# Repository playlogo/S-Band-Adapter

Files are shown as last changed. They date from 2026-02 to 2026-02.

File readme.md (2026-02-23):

# S-Band Adapter

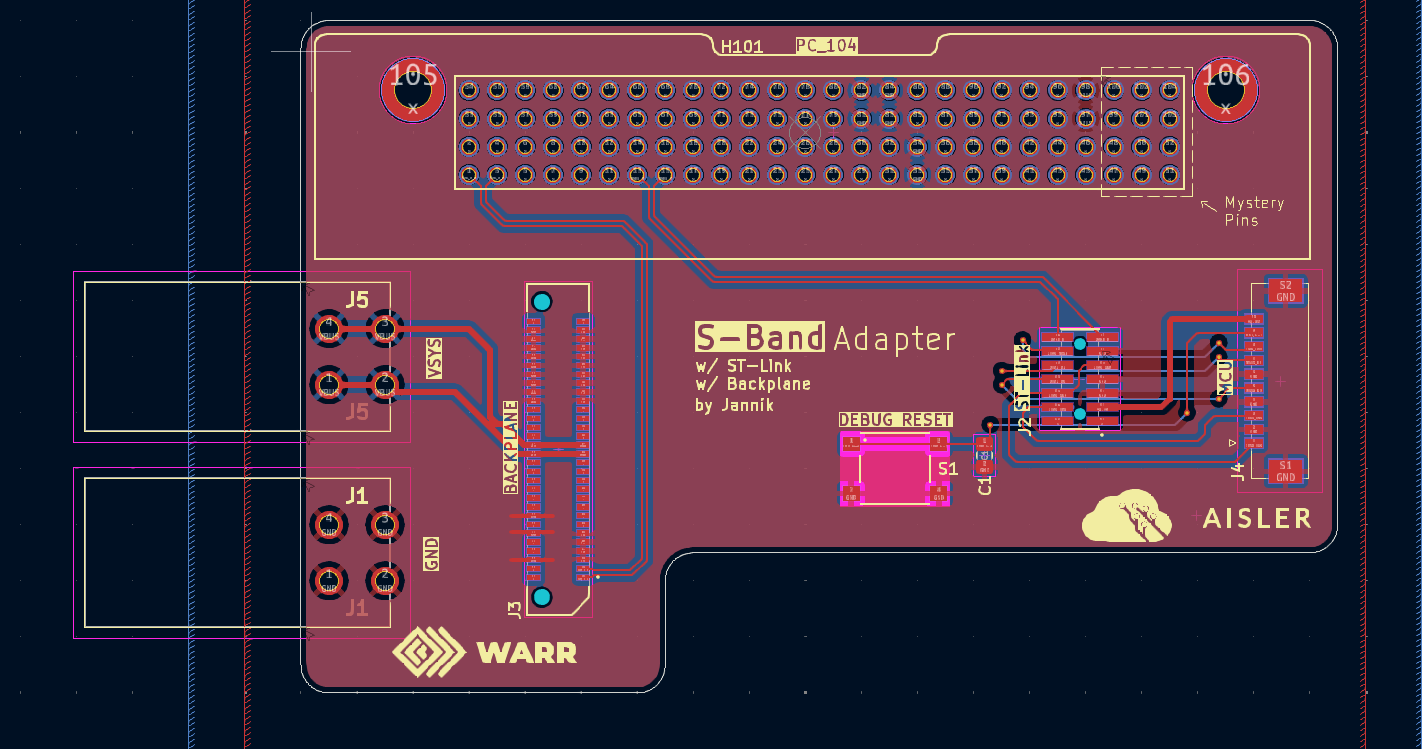
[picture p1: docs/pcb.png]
PCB (https://kicanvas.org/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)

*(image might be outdated, check interactive viewer for latest version)*

**Notes:**

- Under 10x10 cm
- Designed to get stacked *on top* of the S-Band module
- Passes ERC & DRC

**Links:**

- [Interactive PCB View (powered by KiCanvas, always up to date)](https://kicanvas.org/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)

## Components

**SMD Parts:**

- 2x [`CT3151SP`](https://www.digikey.de/de/products/detail/cal-test-electronics/CT3151SP-2/6005547): Banana plugs for VBat & GND - *[footprint](https://componentsearchengine.com/part-view/CT3151SP-2/Cal%20Test)*
- 1x [`FTSH‑107‑01‑L‑DV‑K‑A`](https://www.digikey.de/de/products/detail/samtec-inc/FTSH-107-01-L-DV-K-A/7443623): ST-Link debug connector, uses UART A from PC104 - *[footprint](https://www.snapeda.com/parts/FTSH-107-01-L-DV-K-A/Samtec%20Inc./view-part/?welcome=home&ref=digikey)*
- 1x [`ERF8-030-05.0-L-DV-TR`](https://www.digikey.de/de/products/detail/samtec-inc/ERF8-030-05-0-L-DV-TR/6613294): Move Backplane connector - *[footprint](https://www.snapeda.com/parts/ERF8-030-05.0-L-DV-TR/Samtec%20Inc./view-part/?ref=digikey)*
- 1x [`Molex 53261–1071 10pin`](https://www.digikey.de/de/products/detail/molex/0532611071/699102): S-Band MCU Debug Connector - Same MCU Debug connector on S-Band module - *[footprint](https://www.snapeda.com/parts/532611071/Molex/view-part/?ref=digikey)*
- S-Band connector:
  - Either set of two proper 52 Pin 2.54 Pitch connectors like [these overpriced ones (ESQ-126-39-G-D)](https://www.digikey.de/de/products/detail/samtec-inc/ESQ-126-39-G-D/3601055)
  - Or just a bunch of female and male 2.54mm Pitch connectors cut and combined to get 4 rows x 26 Pins (female for S-Band board, male for this Adapter) - maybe bad idea, since you then cannot stack more than one board on top of the S-Band module...
- 1x 0805 100nF capacitor
- 1x Würth 430152050826 Tactile Switch

**Cables:**

- Adapter Backplane female to Backplane female: Possibly a [Samtec ERCD with 30pos ? - looks very expensive, who even selected the Backplane connector, maybe they know which cable to use...](https://www.samtec.com/products/ercd#)
- S-Band MCU Debug Connector: [Molex PicoBlade 1.25mm, Female-to-Female, 300.00mm Length, 10 Circuits](https://www.molex.com/en-us/products/part-detail/151341003) - Pin order on one side has to be reversed... See image below, `C` should come out on the 3rd from the bottom and not 3rd from top, can easily be done with a screwdrivers

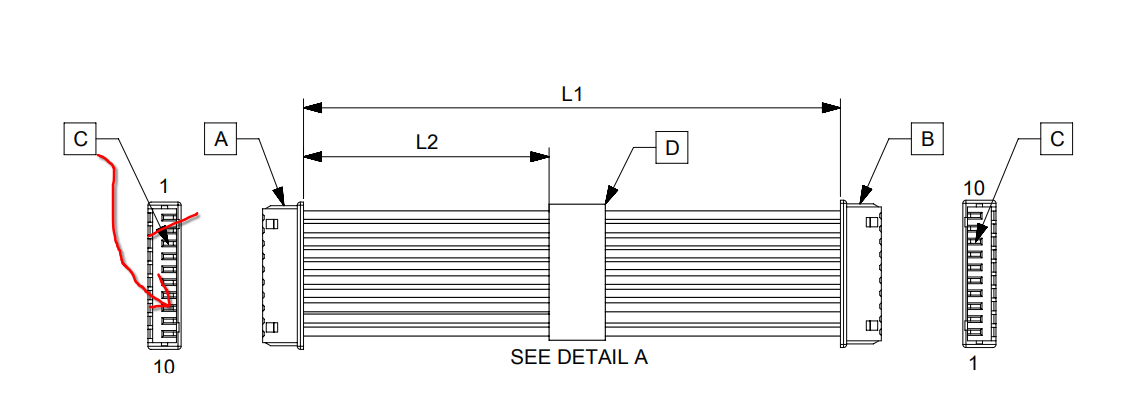
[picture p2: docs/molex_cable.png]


## Schematic

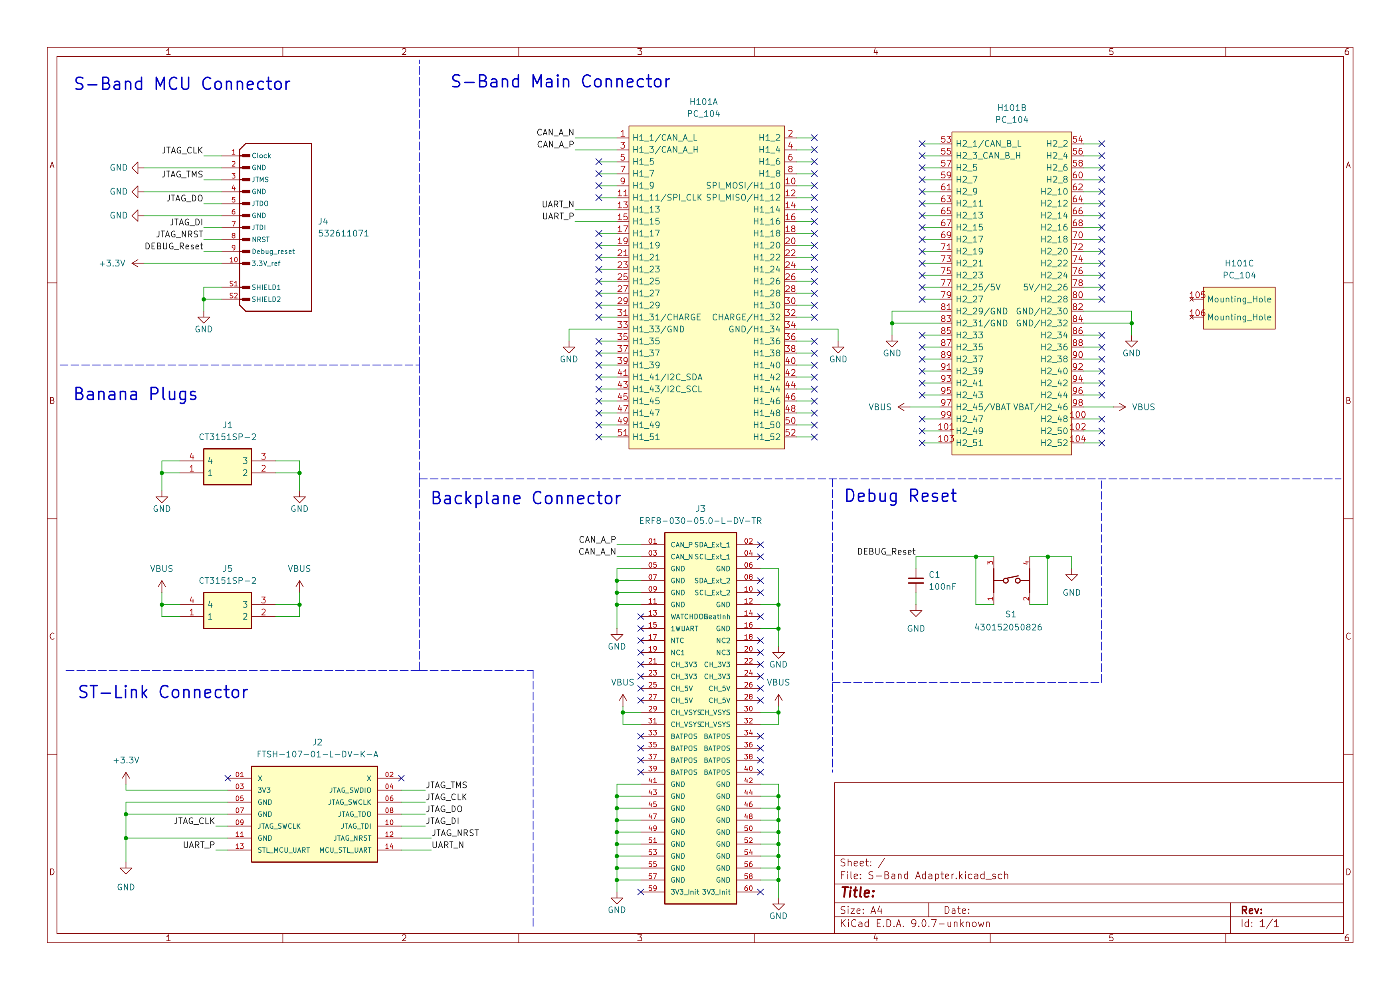
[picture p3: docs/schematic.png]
Scheamtic


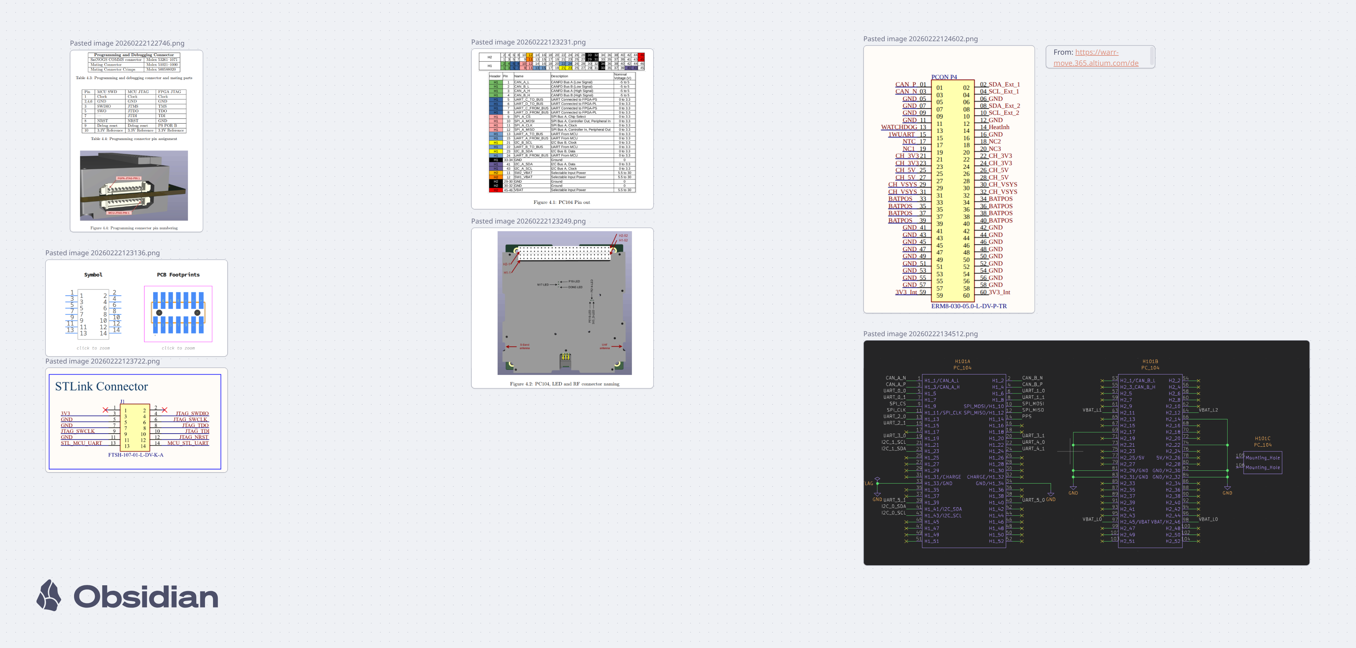
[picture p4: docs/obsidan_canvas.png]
Obsidian canvas


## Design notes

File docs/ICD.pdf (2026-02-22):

## Interface Control Document

SatNOGS COMMS

Version 1.6

SatNOGS COMMS
Interface Control Document

# Contents

1 Changelog | 3
2 Introduction | 5
3 Mechanical interface | 6
4 | Electrical Interfaces | 8
5 FPGA SoM | 16
6 Software Interfaces | 22
Version 1.6 | 1 of 45 | © Libre Space Foundation

SatNOGS COMMS
Interface Control Document
7 Performance Measurements | 25
8 Environmental Specifications | 39
9 Material List | 41
10 Interfaces Data Sheet | 42
Version 1.6 | 2 of 45 | © Libre Space Foundation

SatNOGS COMMS
Interface Control Document

# 1. Changelog

Version | Date | Changes
1.0 | Dec 18, 2023 | No Changes
1.1 | Dec 29, 2023 | No Changes
1.2 | Mar 19, 2024 | Updates for PCB v0.3.1
1.3 | Apr 30, 2024 | No Changes
1.4 | Nov 05, 2024 | No Changes
1.5 | Dec 10, 2024 | • Merged "Subsystem Interface" section with "Electrical interfaces" • Updated mechanical specifications to in- clude the bottom shield • Updated connector part numbers and pinout, added mating connector parts • Added FPGA SoM documentation • Update Software Interfaces chapter • Added "Environmental Specifications", "Performance Measurements", and "Mate- rial List" sections
1.5.1 | Dec 10, 2024 | Fix static GitLab pipeline
1.5.2 | Dec 18, 2024 | No changes
1.6 | | Add more details for RF measurements
Version 1.6 | 3 of 45 | © Libre Space Foundation

SatNOGS COMMS
Interface Control Document

## 1.1 Acronyms

AGC Automatic Gain Control

API Application programming interface

BER Bit Error Rate

BPF Band Pass Filter

CAN Controller Area Network

FPGA Field Programmable Gate Array

GMII Gigabit Media Independent Interface

gRPC gRPC Remote Procedure Calls

HDF5 Hierarchical Data Format

I2C Inter-Integrated Circuit

IC Integrated Circuit

JTAG Joint Test Action Group

LO Local Oscillator

MCU Micro-Controller Unit

PA Power Amplifier

PCB Printed Circuit Board

PDN Power Distribution Network

RF Radio Frequency

RGMII Reduced Gigabit Media-Independent Interface

RSSI Received signal strength indication

SDR Software Defined Radio

SFCG Space Frequency Coordination Group

SMPS Switching Mode Power Supply

SPI Serial Peripheral Interface

TGT Target

UART Universal Asynchronous Receiver Transmitter

UHF Ultra High Frequency

VGA Variable Gain Amplifier

Version 1.6 | 4 of 45 | © Libre Space Foundation

SatNOGS COMMS
Interface Control Document

# 2. Introduction

This Interface Control Document (ICD) defines the interface requirements for integrating SatNOGS COMMS into a CubeSat. In this document, the mechanical interface of the board along with its environmental specifications and materials list are provided. Additionally, the electrical interfaces are described in detail. In particular, the SatNOGS COMMS system included 2 RF interfaces (UHF and S-band), 2 external reference clock interfaces, multiple communication interfaces, and an interface for an FPGA SoM daughter board. For these interfaces, their position on the board along with pinout and other required electrical information are described. Moreover, key performance measurements, such as the power consumption in various operational states, are provided. Finally, the software interfaces of the system are also outlined in this document.

Version 1.6 | 5 of 45 | © Libre Space Foundation

SatNOGS COMMS
Interface Control Document

# 3. Mechanical interface

## 3.1 Dimensions

PCB dimensions, mounting holes, PC104 connector type and location follow LibreCube [1] standard, with the exception of the height of the bottom EMI shield. The PC104 interface connectors are SAMTEC ESQ-126–39–G-D. A mechanical drawing of the outline and mounting hole locations is shown in Figure 3.1 and the respective one for its side view along with an isometric view is shown in Figure 3.2.

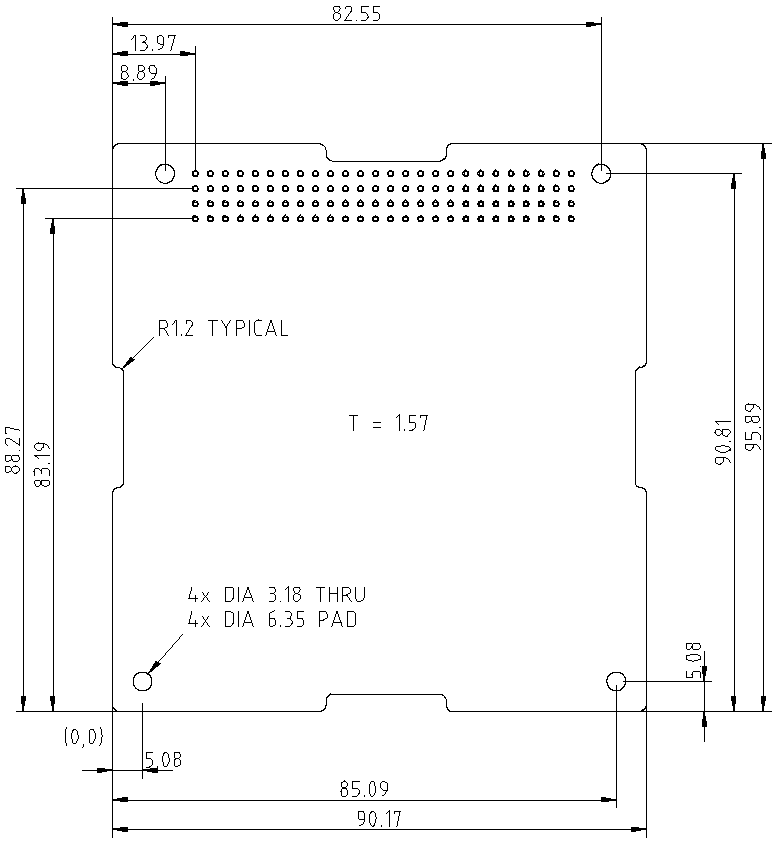
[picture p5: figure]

Figure 3.1: LibreCube mechanical drawing (mm)

Version 1.6 | 6 of 45 | © Libre Space Foundation

SatNOGS COMMS
Interface Control Document

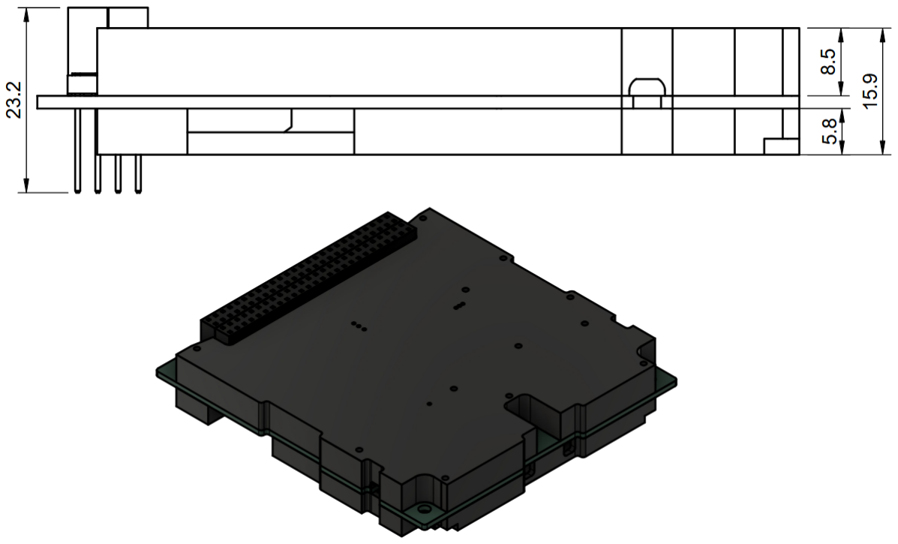
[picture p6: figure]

Figure 3.2: Side view dimensions (mm)

## 3.2 Mass Budget

# | Component | Material | Mass (grams)

1 | PCB | FR4 and copper | 31.1
2 | Passive Components | NA | 7.1
3 | ICs | NA | 16.7
4 | Connector | NA | 6.0
5 | Top Shield | Al 7075 | 80
6 | Bottom Shield | Al 7075 | 50
7 | Screws | A4 Stainless Steel | 4.1
TOTAL | | | 195g (±10g)

Table 3.1: Mass Budget Table

Version 1.6 | 7 of 45 | © Libre Space Foundation

SatNOGS COMMS
Interface Control Document

# 4. Electrical Interfaces

## 4.1 BUS Connector

SatNOGS COMMS connects to a CubeSat bus via a PC–104 connector. The connector type used is the SAMTEC ESQ-126–39–G-D. Regarding pin assignment, it is based on Librecube standard [1]. As far as pin numbering and header naming is concerned, again the Librecube standard is followed and Figure 4.1 contains all necessary information.
For subsystem communication the following interfaces are available on the PC–104 connector:
- Two CAN-FD interfaces backward compatible with CAN-2.0. CAN-FD fulfills interconnect link speed requirements, while subsystems only capable of CAN-2.0 can use SPI for data transfer and CAN-2.0 for control. The CAN transceiver used on SatNOGS COMMS is the TCAN334GDCNT. Additionally, it is possible during the order configuration phase to select whether the 120 Ohm CAN termination resistors will be soldered on SatNOGS COMMS or not. Details about the electrical specifications of the interface can be found in Table 10.3.
- One SPI interface with a maximum link speed of 8Mbps. Details about the electrical specifications of the interface can be found in Table 10.2.
- Two I2C interfaces. Details about the electrical specifications of the interface can be found in Table 10.8.
- Two UART from the MCU. Details about the electrical specifications of the interface can be found in Table 10.7.
- One UART from the FPGA. Details about the electrical specifications of the interface can be found in Table 10.7.

Note that only the CAN interface has been subjected to environmental tests so far.

Version 1.6 | 8 of 45 | © Libre Space Foundation

SatNOGS COMMS
Interface Control Document

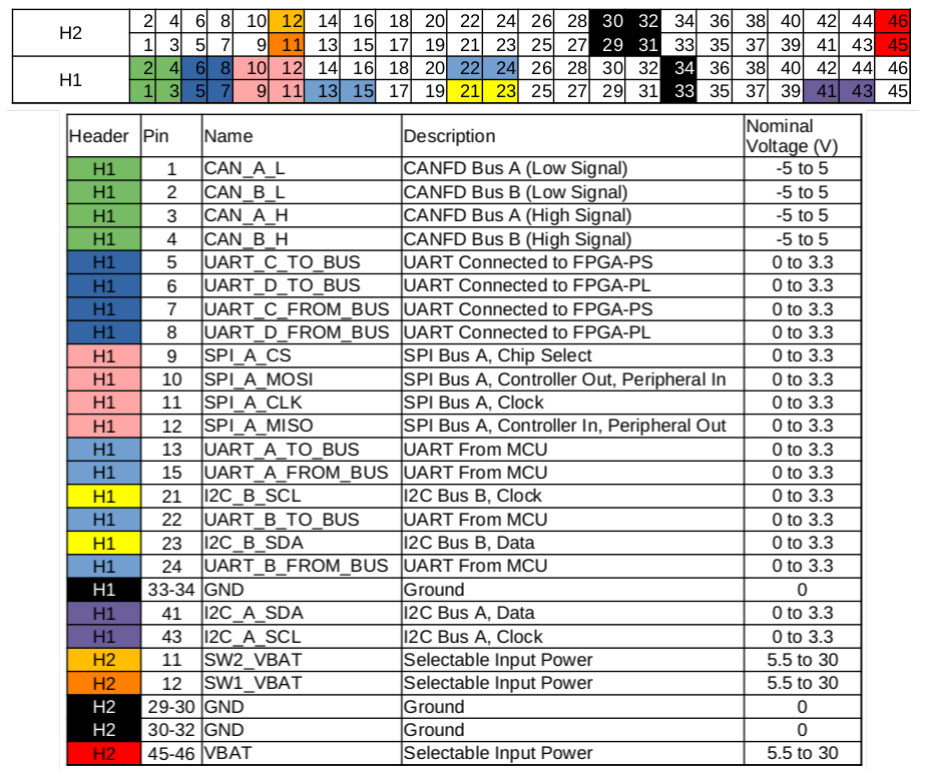
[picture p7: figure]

Figure 4.1: PC104 Pin out

Version 1.6 | 9 of 45 | © Libre Space Foundation

SatNOGS COMMS
Interface Control Document

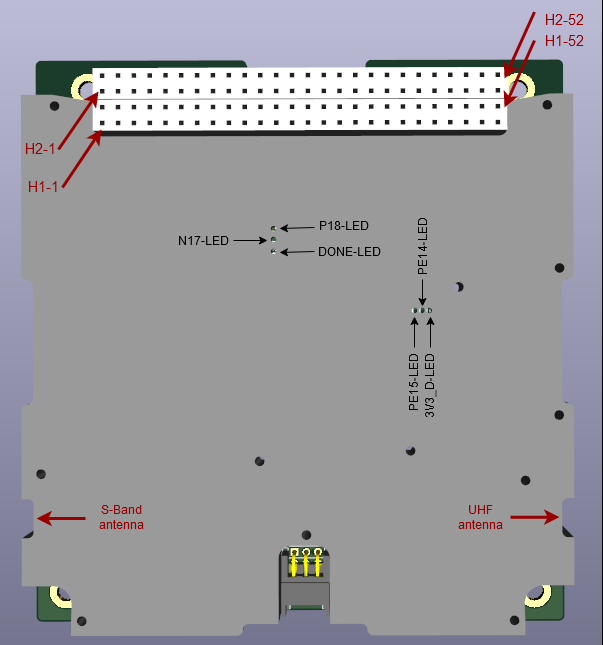
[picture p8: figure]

Figure 4.2: PC104, LED and RF connector naming

Regarding the power supply options, one can notice that three options are available. The user can select among those using solder jumpers, which are soldered during the order configuration stage. As mentioned in Figure 4.1, the input voltage range of SatNOGS COMMS is 5.5V to 30V.

## 4.2 Antenna Deployment Connector

The connector used for the antenna deployment interface along with its mating parts is provide in Table 4.1. The pin assignment is provided in Table 4.2 and the pin numbering is shown in Figure 4.3. The antenna deployment interface exposes two closed loop control endpoints, i.e. two deployment-detection line pairs.
Control signal lines are software configurable as either 3.3V Push-Pull or Open-Drain. Maximum input voltage in Open-Drain configuration is restricted to 5V by an ESD protection diode. Control signal current is limited to 22mA via 220Ω resistor (in the case of a 5V signal).
Detection signal lines are 3.3V compatible and software configured as Pull-Up, Pull-Down or Floating. Pull-Up and Pull-Down resistor value is 40kΩ ± 10kΩ. Each detection line is protected from over-voltage via a 5V ESD protection diode and a 1kΩ resistor.
Version 1.6 | 10 of 45 | © Libre Space Foundation

SatNOGS COMMS
Interface Control Document

Antenna Deployment Connector
SatNOGS COMMS connector | Harwin G125-MH10605L7P
Mating Connector | Harwin G125–2040696L0
Mating Connector Crimps | Harwin G125-FW20450L94

Table 4.1: Antenna deployment connector and mating parts

Pin | Function
1 | GND
2 | GND
3 | Deploy-B
4 | Detect-B
5 | Deploy-A
6 | Detect-A

Table 4.2: Antenna Deploy connector pin assignment

Figure 4.3: Antenna deployment interface pin numbering

## 4.3 Programming and debuging connectors

The connectors used to program and debug the MCU and the FPGA along with their mating parts are provided in Table 4.3. The supported interface for the FPGA is JTAG, while the MCU also supports SWD. Pin assignment is provided in Table 4.4, and pin 1 position is shown in Figure 4.4. Note that the debug reset pin on the MCU JTAG connector refers to a soft reset induced by the debug interface and not to the NRST pin of the MCU.

Version 1.6 | 11 of 45 | © Libre Space Foundation

SatNOGS COMMS
Interface Control Document

Programming and Debugging Connector
SatNOGS COMMS connector | Molex 53261–1071
Mating Connector | Molex 51021–1000
Mating Connector Crimps | Molex 500588020

Table 4.3: Programming and debugging connector and mating parts

Pin | MCU SWD | MCU JTAG | FPGA JTAG
1 | Clock | Clock | Clock
2,4,6 | GND | GND | GND
3 | SWDIO | JTMS | TMS
5 | SWO | JTDO | TDO
7 | — | JTDI | TDI
8 | NRST | NRST | GND
9 | Debug reset | Debug reset | PS POR B
10 | 3.3V Reference | 3.3V Reference | 3.3V Reference

Table 4.4: Programming connector pin assignment

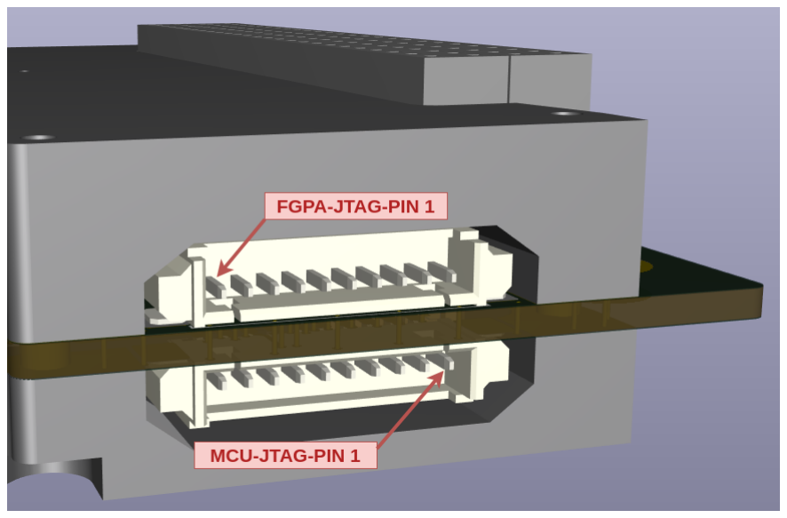
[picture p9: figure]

Figure 4.4: Programming connector pin numbering

## 4.4 RF Connectors

The connector used for the RF communication interfaces along with its mating part are provided in Table 4.5. The position of the UHF and S-Band interface on the board is noted in Figure 4.2.

Version 1.6 | 12 of 45 | © Libre Space Foundation

SatNOGS COMMS
Interface Control Document

Communication RF Connectors
SatNOGS COMMS connector | Molex 73415–0961
Mating Connector | Any MMCX
Mating Connector Crimps | Any MMCX

Table 4.5: Communication RF connectors and mating parts

The connector used for the 26MHz and 1PPS external reference clock interfaces along with its mating part is provided in Table 4.7. The position of the external reference clock interface on the board is noted in Figure 4.5. This figure only shows the cutouts on the EMI shield from which the interface cables exit the system. During assembly, the cables are connected before the EMI shield is placed and secured.
Some additional information on the external reference clock interface, is provided in Table 4.6.
Interface | Voltage Limit | Signal Type | Input Interface
1PPS | 0V to 3.3V | Rectanglular pulse | LMK1C1102DQF
26MHz | 600mV to 1500mV (peak to peak) AC Coupling | Rectanglular pulse Sine Clipped Sine | TS5A3157DCKR

Table 4.6: External Clock Interfaces

Reference Clock RF Connectors
SatNOGS COMMS connector | Wurth 66011102111302
Mating Connector | Same as mating crimp
Mating Connector Crimps | AmphenolRF 262111 MMCX Right Angle Crimp Plug RG-316DS RD-316 50 Ohm

Table 4.7: Reference clock RF connectors and mating parts

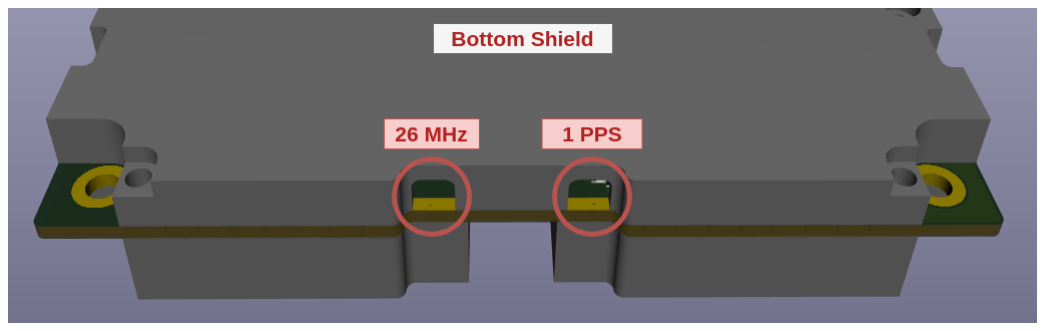
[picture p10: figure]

Figure 4.5: External clock reference interface

Version 1.6 | 13 of 45 | © Libre Space Foundation

SatNOGS COMMS
Interface Control Document

## 4.5 RGMII, UART & eMMC Connector

SatNOGS COMMS provides an RGMII interface which is connected to the PS part of the Zync SoC and, internally, it is fed by a GMII to RGMII adapter, which is wired to an IEEE 802.3–2008 [2] compliant gigabit ethernet controller. Up to 100 Mbps throughput on 1.8V operation has been achieved through this interface during testing.
The RGMII interface, a UART interface for debugging the SoM, along with some lines to access the eMMC memory are exposed on the connector listed in Table 4.8. The pinout of said connector is provided in Table 4.9 and the position of pin 1 is shown in Figure 4.6.

RGMII, UART, eMMC Connector
SatNOGS COMMS connector | Harwin G125-MH12605L3R
Mating Connector | Harwin G125–2042696L0
Mating Connector Crimps | Harwin G125-FW20150F94

Table 4.8: RGMII, UART, eMMC connector and mating parts

Pin | Function
1 | PHY_RESET
2 | 1.8V output
3 | RGMII-MDC
4, 7, 8, 22 | GND
5 | RGMII-MDIO
6 | PHY_INT
9 | RGMII-TXD0 from SoM
10 | RGMII-RXCLK to SoM
11 | RGMII-TXD1 from SoM
12 | RGMII-RXCTL to SoM
13 | RGMII-TXD2 from SoM
14 | RGMII-RXD0 to SoM
15 | RGMII-TXD3 from SoM
16 | RGMII-RXD1 to SoM
17 | RGMII-TXCLK from SoM
18 | RGMII-RXD2 to SoM
19 | RGMII-TXCTL from SoM
20 | RGMII-RXD3 to SoM
21 | MCU_MMC-D0
23 | MCU_MMC-CMD
24 | UART-RX to SoM
25 | MCU_MMC-CK
26 | UART-TX from SoM

Table 4.9: RGMII, UART & eMMC connector pinout

Version 1.6 | 14 of 45 | © Libre Space Foundation

SatNOGS COMMS
Interface Control Document

Figure 4.6: RGMII, UART & eMMC connector pin 1

## 4.6 ESD & Power protections

### 4.6.1 ESD

Most of the interfaces of SatNOGS COMMS include ESD protection in the form of clamping diodes placed as close as possible to the connectors. In particular, the protected interfaces are:

- MCU and FPGA JTAG
- PC–104 SPI, I2C and UART. Also resistors are included in-series after the diodes and before the components.
- Antenna deployment

Regarding the CAN interface on the PC–104, the selected CAN driver (TCAN334G) incorporates ESD protection.
Regarding the external reference clock 26MHz and 1PPS, the selected multiplexer and clock buffer incorporated ESD protection.

### 4.6.2 Power protection

The power system of SatNOGS COMMS is paired with an elaborate protection scheme able to protect the downstream components from overvoltage, undervoltage and excessive current draw. All major power rails on the board are automatically reset in the event of excessive current draw or overvoltage, while an MCU signal is required in addition to a proper voltage level for the RF and FPGA power rails to be enabled. For further details on the operation of the power protection system along with an FMEA analysis, please refer to the System Design Document.

Version 1.6 | 15 of 45 | © Libre Space Foundation

SatNOGS COMMS
Interface Control Document

# 5. FPGA SoM

This chapter details the various interfaces related to the FPGA SoM that can be hosted on SatNOGS COMMS. The electrical and mechanical interface characteristics required for a user to employ their own SoM on SatNOGS COMMS are provided.

## 5.1 RF Functionality

The baseband transceiver functionalities are listed below:

- Modulation: GMSK/GFSK, BPSK, QPSK
- Tx: ECC, CCSDS CC1/2 w/ and w/o RS, Rx: only CCSDS RS
- Framing encapsulation: CCSDS, IEEE 802.15.4
- Data Rates: UHF, up to 50 kbps, S-Band, up to 1 Mbps

In the default SatNOGS COMMS configuration with the Alinx AC7Z020, the SoM provides a 13-bit I/Q data interface with a sampling frequency up to 4MHz through which additional RF functionalities can be implemented.

## 5.2 Mechanical Interface

The FPGA SoM is mechanically attached to SatNOGS COMMS through nuts, bolts, and threaded spacers. In particular, the following parts are used:

- Nut M2 DIN934
- Bolt M2L8 DIN912
- Female to Female M2 L3, Knurled, Brass, Round Spacer

For the default SoM used in SatNOGS COMMS (the Alinx AC7Z020), the mounting is performed by placing the bold such that the bolt head contacts the bottom side of the board and the nut contacts the top side of the SoM, as shown in Figure 5.1. For the flight configuration, glue is applied to the nut and bolt. Regarding the relative position of the SoM mounting holes to the mezzanine connectors, a SoM KiCAD footprint has been created as part of the LibreWave project and it can be found in lsf-kicad-lib (https://gitlab.com/librespacefoundation/lsf-kicad-lib) under the footprint name LibreWave-SoM.

Version 1.6 | 16 of 45 | © Libre Space Foundation

SatNOGS COMMS
Interface Control Document

Figure 5.1: AC7Z020 SoM mounting

## 5.3 Electrical Interface

### 5.3.1 Mezzanine Connector Pinout

The connector used to interface SatNOGS COMMS with the FPGA SoM along with its mating part are provided in Table 5.1.
The functionalities of the mezzanine connector pins are provided in Table 5.2 and Table 5.3, while the naming of the two headers of the mezzanine connectors are shown in Figure 5.2.

RGMII, UART, eMMC Connector
SatNOGS COMMS connector | Panasonic AXK6A2337YG
Mating Connector | Panasonic AXK5A2137YG
Mating Connector Crimps | N/A

Table 5.1: FPGA SoM mezzanine connector and mating part

Version 1.6 | 17 of 45 | © Libre Space Foundation

SatNOGS COMMS
Interface Control Document

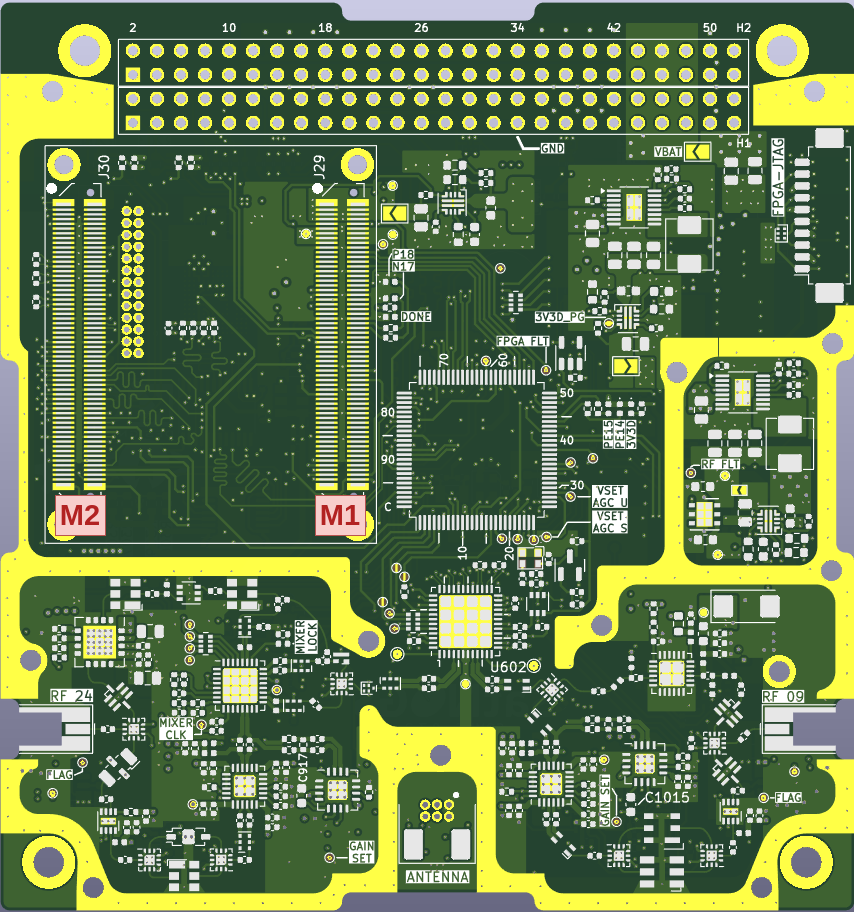
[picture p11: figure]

Figure 5.2: Mezzanine connector header numbering

Version 1.6 | 18 of 45 | © Libre Space Foundation

SatNOGS COMMS
Interface Control Document

H1

Header no | Overall no | Functionality
1, 2, 3, 4, 5, 6, 7, 8 | 1, 2, 3, 4,
| 5, 6, 7, 8 | 5V SoM input
11, 13, 15, 17 | 11, 13, 15, 17 | 3.3V SoM input
12, 14, 16, 18 | 12, 14, 16, 18 | 2.5V SoM input
9, 10, 19, 20, 29, 30, 39, 40, 49, 50, 59, 60, 69, 70, 79, 80, 89, 90, 99, 100, 109, 110 | 9, 10, 19, 20,
| 29, 30, 39, 40,
| 49, 50, 59, 60,
| 69, 70, 79, 80,
| 89, 90, 99, 100,
| 109, 110 | GND
22 | 22 | SPI-SEL
24 | 24 | SPI-MOSI
28 | 28 | SPI-MISO
37 | 37 | 1 PPS SoM clock input line 2
41 | 41 | SPI-CLK
52 | 52 | LED_1 output
54 | 54 | LED_2 output
55 | 55 | UART_2 RX to SoM
57 | 57 | UART_2 TX from SoM
72 | 72 | RX_INT (used as a generic IO
| | or to indicate an interrupt due to RF RX)
76 | 76 | IP_RESET (used as a generic IO
| | or to reset the IP cores)
81 | 81 | 100 MHz SoM clock input
111 | 111 | JTAG-TCK
113 | 113 | JTAG-TMS
115 | 115 | JTAG-TDO
116 | 116 | PS_POR_B (specific to some Xilinx FPGAs)
117 | 117 | JTAG-TDI
118 | 118 | FPGA_DONE (also drives a LED)

Table 5.2: Mezzanine connector H1 pinout

Version 1.6 | 19 of 45 | © Libre Space Foundation

SatNOGS COMMS
Interface Control Document

H2

Header pin | Connector pin | Functionality
9, 10, 29, 20, 29, 30, 39, 40, 49, 50, 59, 60, 69, 70, 79, 80, 89, 90, 99, 100, 109, 110, | 129, 130, 139, 140, 149, 150,
| 159, 160, 169, 170, 179, 180,
| 189, 190, 199, 200, 209, 210,
| 219, 220, 229, 230 | GND
1 | 121 | LVDS-TXDP from SoM
3 | 123 | LVDS-TXDN from SoM
25 | 145 | LVDS-RXDP Sband to SoM
27 | 147 | LVDS-RXDN Sband to SoM
31 | 151 | LVDS-RXDN UHF to SoM
33 | 153 | LVDS-RXDP UHF to SoM
41 | 161 | LVDS-RXCLKN to SoM
43 | 163 | LVDS-RXCLKP to SoM
52 | 172 | LVDS-TXCLKP from SoM
54 | 174 | LVDS-TXCLKN from SoM
61 | 181 | RGMII-RXCLK to SoM
63 | 183 | RGMII-RXCTL to SoM
65 | 185 | RGMII-RXD0 to SoM
66 | 186 | PHY_INT
67 | 187 | RGMII-RXD1 to SoM
71 | 191 | RGMII-RXD2 to SoM
72 | 192 | 1 PPS SoM clock input line 1
73 | 193 | RGMII-RXD3 to SoM
74 | 194 | MMC CK
75 | 195 | RGMII-TXCTL from SoM
76 | 196 | MMC D0
77 | 197 | RGMII-TXCLK from SoM
78 | 198 | MMC CMD
81 | 201 | RGMII-TXD3 from SoM
83 | 203 | RGMII-TXD2 from SoM
84 | 204 | MMC D2
85 | 205 | RGMII-TXD1 from SoM
87 | 207 | RGMII-TXD0 from SoM
92 | 212 | MMC D1
94 | 214 | PHY_RESET
96 | 216 | UART_1 TX from SoM
98 | 218 | UART_1 RX to SoM
102 | 222 | RGMII-MDC
112 | 232 | MMC D3
114 | 234 | UART_0 RX to SoM
116 | 236 | UART_0 TX from SoM
118 | 238 | RGMII-MDIO
119, 120 | 239, 240 | Configurable Pull Up/Down

Table 5.3: Mezzanine connector H2 pinout

Version 1.6 | 20 of 45 | © Libre Space Foundation

SatNOGS COMMS
Interface Control Document

### 5.3.2 SoM Power Interfaces

The SoM is powered via a PDN implemented on SatNOGS COMMS. The voltage levels provided by this PDN along with their current limits are listed below:

- 5V power channel: SMPS (LT8610EMSE#PBF), shared with the RF subsystem, protected against overvoltage, undervoltage, and overcurrent events via an e-fuse (TPS259470A). Overvoltage limits range from 5.3 to 5.47V. Undervoltage limits are 4.75V (for a rising edge) and 4.5V (for a falling edge). Additionally, an undevoltage limit of 5.7V has been set for the input of the SMPS. The current limit stands at 0.59 A. Note that the 3.3V and 2.5V power channels draw from the 5V one, so the aforementined current limit cannot be fully exploited by the 5V power channel.
- 3.3V power channel: LDO (LD39100PU33RY), with a current output capability dependent on the ambient temperature. A current capability of 0.48 A is obtained for the case of 80 C ambient temperature.
- 2.5V power channel: LDO (MIC5320-JGYD6), with a current output capacity dependent on the ambient temperature. A current capability of 0.26 A is obtained for the case of 80 C ambient temperature.
Version 1.6 | 21 of 45 | © Libre Space Foundation

SatNOGS COMMS
Interface Control Document

# 6. Software Interfaces

## 6.1 Space Segment

SatNOGS-COMMS provide a reference firmware[3] based on the Zephyr-RTOS[4]. This firmware covers the majority of the functionality required from a COMMS subsystem. Moreover, the firmware provides extensive functionality to operate as OBC too, if the mission requires it. Special attention has been given on the design of the firmware, so mission specific code can be added, adapting to the user needs. For more information refer to the main firmware documentation available at [5].
In case a mission or user requirements dictate significant firmware modifications or even another RTOS, SatNOGS-COMMS provide the SatNOGS COMMS Control Library[6]. This is an interface library that controls the SatNOGS COMMS transceiver components. It relies on a peripheral abstraction layer, allowing users of the SatNOGS COMMS to build their own firmware with minimal effort.

## 6.2 Ground Segment

### 6.2.1 Telemetry API

SatNOGS provides an API for receiving acquired telemetry as well as signal acquisition parameters. For non real-time operation, raw telemetry data is uploaded directly to SatNOGS DB servers by SatNOGS Client, on predefined intervals. This API endpoint accepts HDF5 formatted files which include additional information and metadata of the scheduled SatNOGS Network observation. The telemetry data are then processed and forward to the InfluxDB database of SatNOGS Dashboards in order to be visualized. For real-time operation, SatNOGS Client forwards the telemetry data to a SatNOGS Yamcs server. The SatNOGS Yamcs server receives the data through a data link plugin which provides a gRPC interface for telemetry. In this case, telemetry data is still eventually forwarded to SatNOGS DB via the Yamcs server and a SatNOGS DB API data link plugin.

### 6.2.2 Telecommand API

SatNOGS provides an API allowing telecommand data transmission. SatNOGS Client gRPC interface is used to receive telecommands. These commands are

Version 1.6 | 22 of 45 | © Libre Space Foundation

SatNOGS COMMS
Interface Control Document

sent by the SatNOGS Yamcs server via a gRPC data link plugin. The client then forwards the telecommands to SatNOGS Radio in order to be encoded and transmitted via the SDR.

### 6.2.3 Telecommand and Telemetry Format

The default firmware of the SatNOGS-COMMS utilizes the CCSDS XTCE[7] to describe the available telecommands and telemetry responses, as well as the internal structure of each frame. Yamcs provides seamless integration with the CCSDS XTCE.

### 6.2.4 Control Software

For the reference firmware[3] the SatNOGS COMMS project provides a Yamcsbased control software[8]. This Yamcs based control software can be used to telecommand the transceiver from any of the available interfaces (RF, CAN, UART) as well as receive telemetry. This is accomplished using the CCSDS XTCE definition that ships with the reference firmware. The purpose of this software it to act as a starting point, so missions can build easily the entire mission control with minimal effort.

## 6.3 Health Status Telemetry

### 6.3.1 Temperature Sensor Positions

To interpret the temperature values received in the health status telemetry, it is required to know the positions of the temperature sensors on the board. There are three sensors used to measure ambient (PCB) temperature, UHF PA temperature, and S-band PA temperature. The positions of the aforementioned sensors are depived in Figure 6.1.

Version 1.6 | 23 of 45 | © Libre Space Foundation

SatNOGS COMMS
Interface Control Document

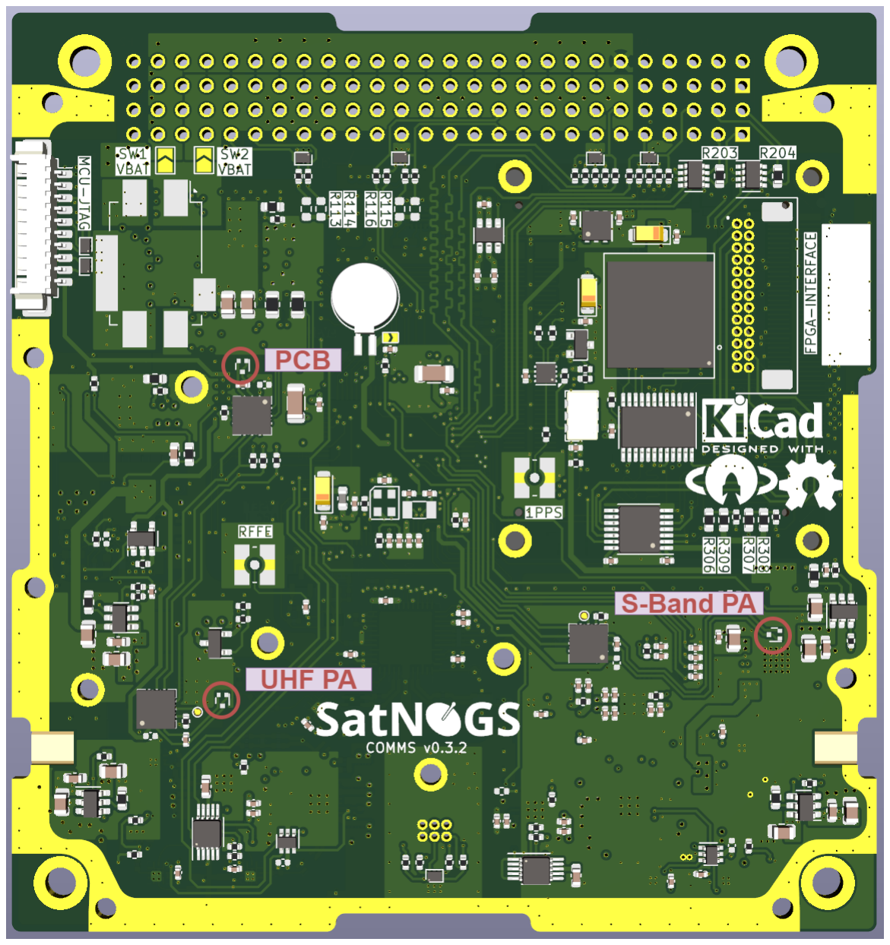
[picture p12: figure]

Figure 6.1: Temperature sensor positions

Version 1.6 | 24 of 45 | © Libre Space Foundation

SatNOGS COMMS
Interface Control Document

# 7. Performance Measurements

This chapter includes measurements related to the performance of the system, such as power consumption and RF characteristics.

## 7.1 Power Measurements

The power consumption of the system has been measured in various operational states. These measurements listed in Table 7.1 below refer to a 12V supply voltage. For a more detailed presentation along with comments on the test conditions refer to this spreadsheet. (https://cloud.libre.space/s/Rj7w5mWLiB8LQnf) Note that the measurements were made in v0.3, but the differences with the most recent version are very minor.

State no. | Avg Current [mA] | Peak Current [mA] | State Description
State 1 | 67 | NA | MCU peripherals initialized
State 2 | 57 | NA | State 1 + eMMC initialized
State 3 | NA | 91 | State 2 + eMMC write
State 4 | NA | 91 | State 2 + eMMC read
State 5 | 143 | NA | State 2 + FPGA on
State 6 | 203 | NA | State 2 + FPGA running petalinux
State 7 | 230 | NA | State 2 + FPGA stress petalinux
State 8 | 74 | NA | State 1 + RF open
State 9 | 71 | NA | State 8 + init AT86
State 10 | 370 | 641 | State 9 + full power TX UHF baseband
State 11 | 247 | NA | State 9 + RX UHF
State 12 | 185 | NA | State 9 + RX UHF
State 13 | 250 | NA | State 9 + RX UHF
State 14 | NA | NA | State 9 + RX UHF
State 15 | 467 | 718 | State 9 + fullpower TX S baseband
State 16 | 303 | NA | State 9 + RX S
State 17 | 267 | NA | State 9 + RX S
State 18 | 305 | NA | State 9 + RX S
State 19 | 245 | NA | State 9 + RX S
State 20 | 574 | 750 | State 15 + FPGA running petalinux
State 21 | 602 | 773 | State 15 + FPGA stress petalinux

Table 7.1: Current consumption in various operational states

Version 1.6 | 25 of 45 | © Libre Space Foundation

SatNOGS COMMS
Interface Control Document

## 7.2 Inrush current

Inrush current is a brief high current surge drawn when the device is turned ON. It generally occurs due to uncharged capacitors at the input of power supplies. The setup of the inrush current measurement was according to ECSS-E-ST-20–07C Rev.2. The setup consists of a Line Impedance Stabilization Network (LISN), a mechanical switch, a current probe and an oscilloscope for data acquisition. In this case, the current probe was replaced by two voltage probes and a 0.1 Ohm shunt resistor (RS010R1000FE12). To measure the current, the switch is pressed ON to power the device. A 12V battery was used as the power supply.
The inrush current waveform (Figure 7.1), can be characterized by two pulses. The first one, which is the main current draw, and the second one of much smaller amplitude. The small current draw, before the pulse emergence, is associated with the accuracy error of the oscilloscope and slight smoothing applied to the data for better visual representation.
The first current pulse reaches 13A and lasts around 100 µs. Immediately after, it reaches negative values up to -2A. The second pulse reaches around 3A and also lasts around 100 µs. After that, the board stabilizes to the nominal power consumption, when flashed with the particular firmware. It should be noted that the input voltage rise, when pressing the switch, is around 40 us. In case the input voltage has slowly risen to the desired level, the inrush current is much lower, although the number of pulses that occur increases. More details in https://gitlab.com/librespacefoundation/satnogs-comms/satnogs-comms-hardware/-/issues/490.

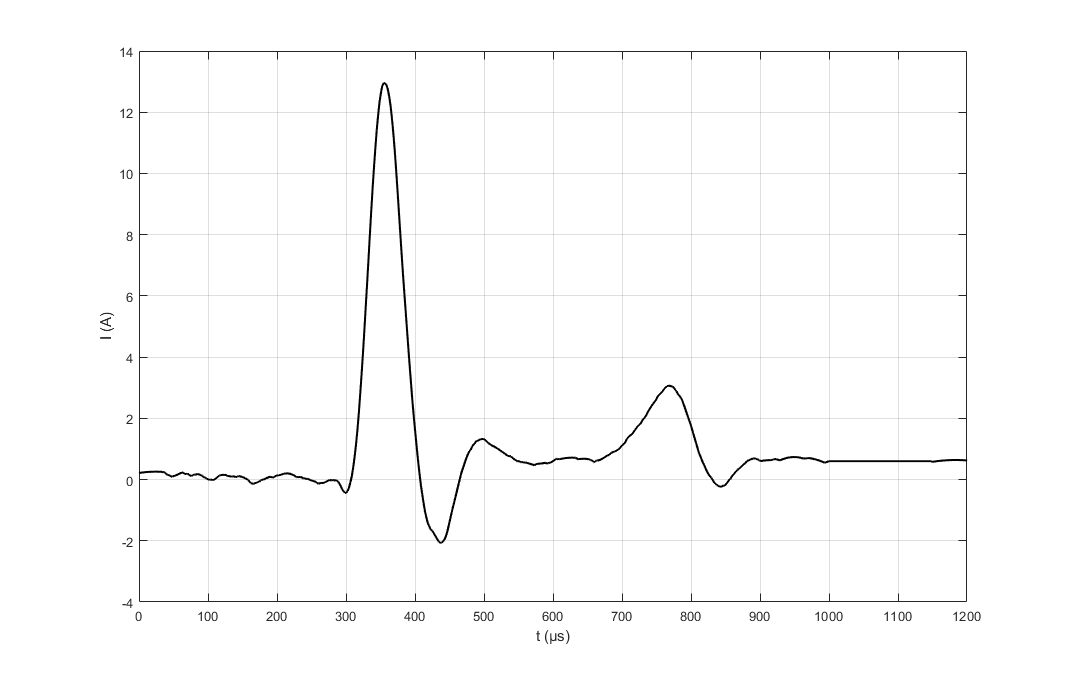
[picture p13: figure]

Figure 7.1: Inrush current of SatNOGS COMMS v0.3.2 — PHASMA version when first turned ON

Version 1.6 | 26 of 45 | © Libre Space Foundation

SatNOGS COMMS
Interface Control Document

## 7.3 RF Measurements

### 7.3.1 UHF Radio-Transmitter

The UHF radio is compliant with the SFCG 21–2R4 recommendations, peak indicated by the marker 2–1 in Figure 7.2 and the markers 2–1, 3–1, 4–1 in Figure 7.3.

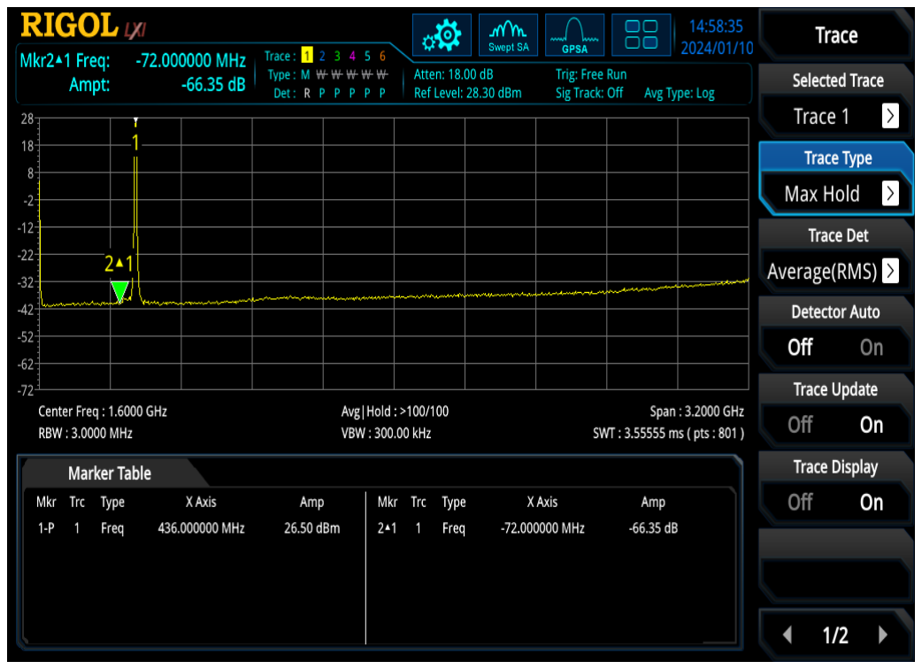
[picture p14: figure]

Figure 7.2: UHF spurious emissions, FSK–2, m = 1, TX power = +31 dBm, symbol rate = 50 kHz

Version 1.6 | 27 of 45 | © Libre Space Foundation

SatNOGS COMMS
Interface Control Document

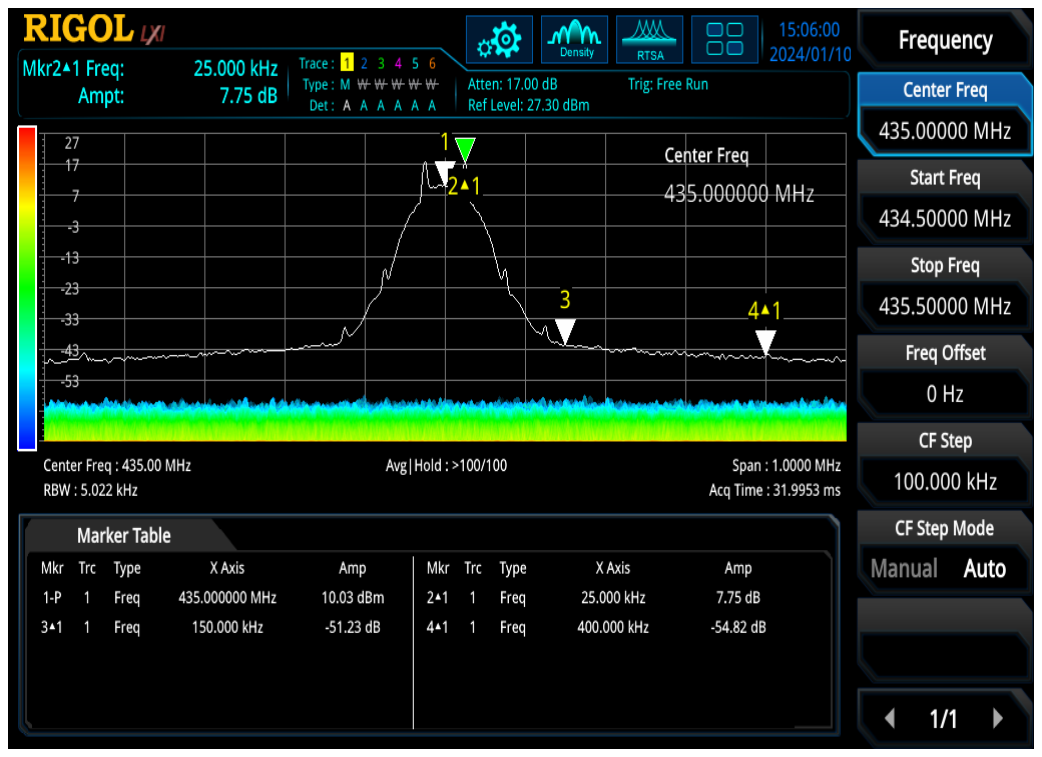
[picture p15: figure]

Figure 7.3: UHF spurious emissions, FSK–2, m = 1, TX power = +31 dBm, symbol rate = 50 kHz

The RF output power is not affected by the modulation index (0.5, 1, 1.5,
2) in FSK at 50 ksps. The following diagrams, Figure 7.4 and Figure 7.5, show that the RF output power and the DC power consumption are affected by the operating frequency, 401 and 435MHz. The measurements are done:
- with peak detector and maximum hold as trace type
- the measurement bandwidth (integrated) is 50kHz (FSK-2 at 50ksps) on 200kHz span
- temperature: 25 ◦C
- Dwell time: 60secs
- the DC power consumption is measured with joulescope and it is the average value of plateau, Figure 7.6
Version 1.6 | 28 of 45 | © Libre Space Foundation

SatNOGS COMMS
Interface Control Document

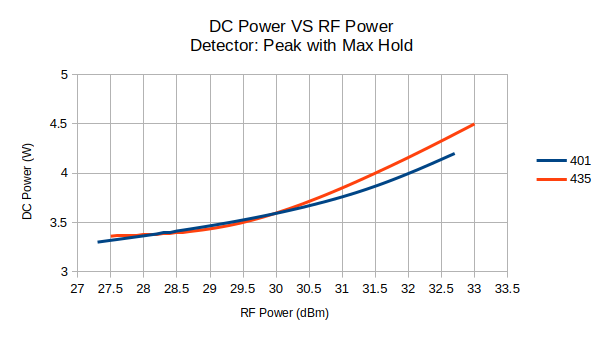
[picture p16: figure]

Figure 7.4: DC power vs TX RF power on UHF radio

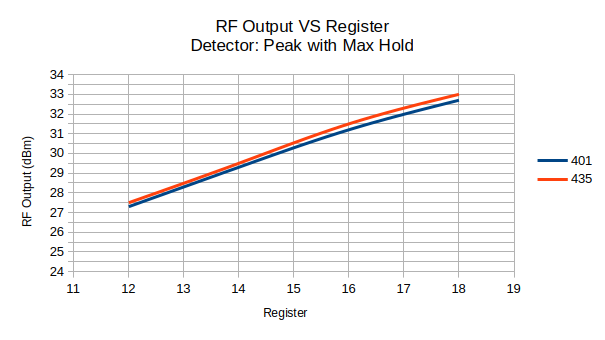
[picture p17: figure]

Figure 7.5: TX RF power vs AT86RF215 TX register on UHF radio

Version 1.6 | 29 of 45 | © Libre Space Foundation

SatNOGS COMMS
Interface Control Document

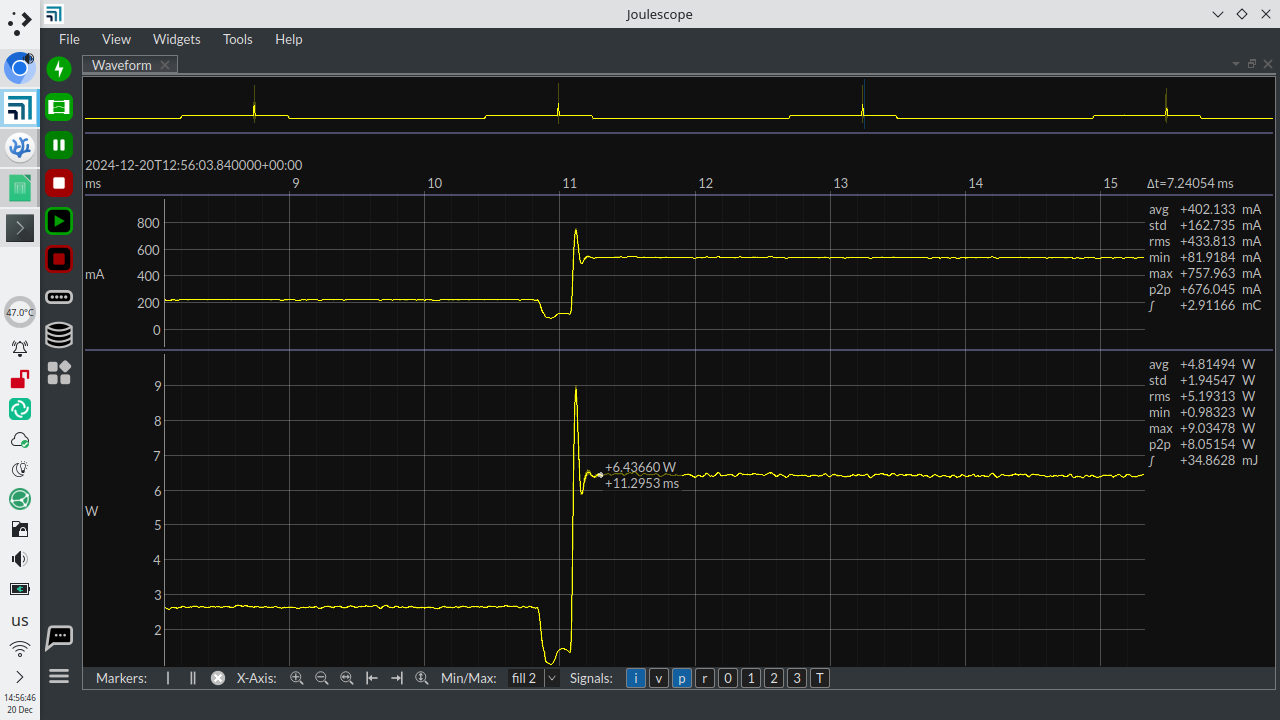
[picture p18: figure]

Figure 7.6: DC power consumption plateau measurement (an example)

The frequency step is 100Hz in the range 400MHz to 440MHz as defined by AT86RF215 IC.

### 7.3.2 UHF Radio-Receiver

The receive RF front end, can operate in two modes:

- AGC is enabled, Figure 7.7.
- AGC is disabled, and VGA is controlled by MCU, Figure 7.8.

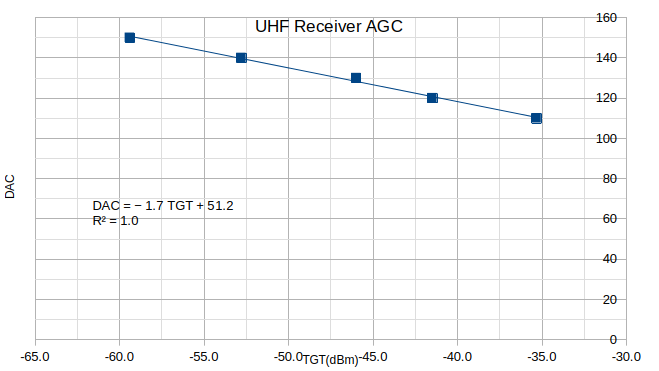
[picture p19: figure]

Figure 7.7: UHF AGC-ON, DAC 8-bit

Version 1.6 | 30 of 45 | © Libre Space Foundation

SatNOGS COMMS
Interface Control Document

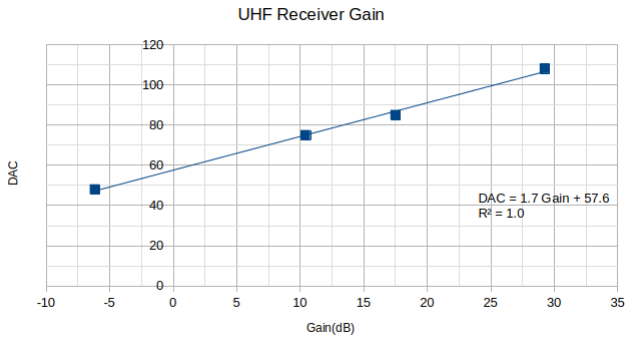
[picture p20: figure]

Figure 7.8: UHF AGC-OFF, DAC 8-bit

The suggested mode is AGC ON with TGT level −55dBm to achieve the largest dynamic range of 50dB. Some critical characteristics:

Noise Figure (dB) | 1.8
Maximum input (dBm) | +20

Table 7.2: UHF receiver

The TGT level is measured by using the RSSI of AT86RF215 with tolerance of ±5dB. The following table, Table 7.3, shows the DC power consumption in different RF input when the AGC in enabled and the output target is set on -52dBm ±5dB.

RF input (dBm) | RSSI (dBm) | Gain (dB) | DC power (W)
-20 | -41 | -21 | 1.69
-30 | -51 | -21 | 1.73
-40 | -51 | -11 | 1.8
-50 | -51 | -1 | 1.88
-60 | -51 | 9 | 1.98
-70 | -51 | 19 | 2.1
-80 | -51 | 29 | 2.25
-90 | -53 | 37 | 2.5
-100 | -61 | 39 | 2.5
-110 | -70 | 40 | 2.5

Table 7.3: RX UHF Radio dynamic range and DC power consumption, AGC ON with TGT -52dBm

The measurements are done:

- with CW RF input signal
- by using the wide BPF
Version 1.6 | 31 of 45 | © Libre Space Foundation

SatNOGS COMMS
Interface Control Document
- temperature: 25 ◦C
- Dwell time: 60secs
- the DC power consumption is measured with joulescope and it is the average value of plateau, Figure 7.6

The frequency step is 100Hz in the range 400MHz to 440MHz as defined by AT86RF215 IC.
Another important aspect is the BER performance of receiver. The following diagram and table, Figure 7.9 and Table 7.4, present the receiver sensitivity in different modulations.

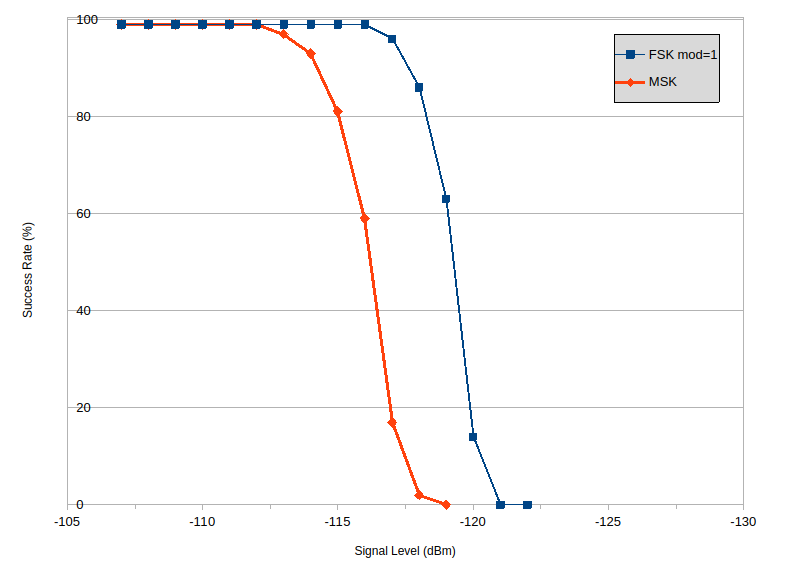
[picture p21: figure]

Figure 7.9: UHF Frame success rate for various signal levels

Modulation | ∆f (kHz) | Success Rate | Signal Level (dBm)
FSK—2, 50ksps | ±10 | 1099 of 1100 | -100
MSK, 50ksps | ±10 | 1100 of 1100 | -110

Table 7.4: RX UHF Radio Frequency offset sensitivity

Note:Better sensitivity is under investigation by the SatNOGS COMMS software team.

### 7.3.3 S-Band Radio-Transmitter

The S Band radio is compliant with the SFCG 21–2R4 recommendations, peak indicated by marker 2–1 in Figure 7.10 and markers 2–1, 3–1, 4–1 in Figure 7.11.

Version 1.6 | | 32 of 45 | © Libre Space Foundation

SatNOGS COMMS
Interface Control Document

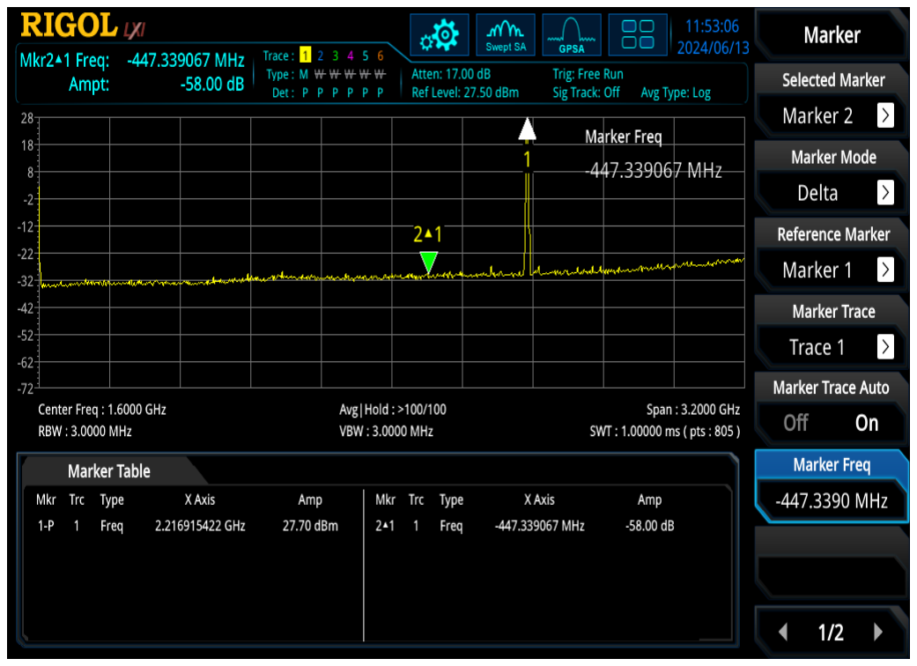
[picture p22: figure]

Figure 7.10: S Band spurious emissions with FSK–2, m = 0.5, TX power = +33 dBm, 400 kHz symbol rate

Figure 7.11: S Band spectrum mask for MSK, Input Power = 6.5dBm, symbol rate = 400 kHz

The RF output power is measured only on MSK at 400ksps. The following diagrams, Figure 7.12, Figure 7.13 and Figure 7.14, show that the RF output power and the DC power consumption are affected by the operating frequency, 2200MHz and 2290MHz. The measurements are done:

- with peak detector and maximum hold as trace type
- the measurement bandwidth (integrated) is 400kHz (MSK at 400ksps) on 600kHz span
Version 1.6 | 33 of 45 | © Libre Space Foundation

SatNOGS COMMS
Interface Control Document
- temperature: 25 ◦C
- Dwell time 60 secs
- the DC power consumption is measured with joulescope and it is the average value of plateau, Figure 7.6

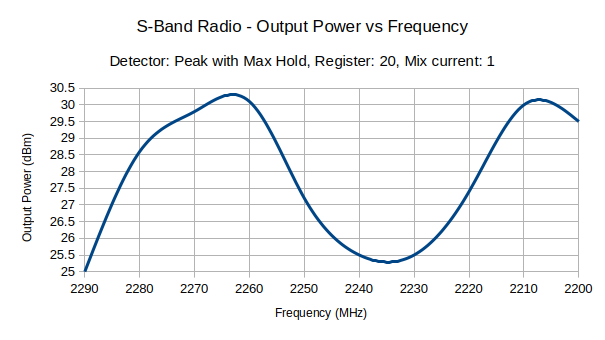
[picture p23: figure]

Figure 7.12: TX RF power vs Frequency on S-Band radio

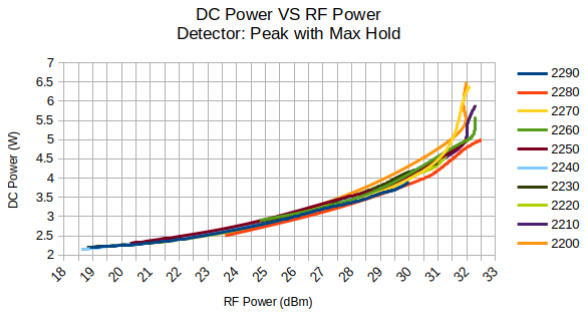
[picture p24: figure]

Figure 7.13: DC power vs TX RF power on S-Band radio

Version 1.6 | 34 of 45 | © Libre Space Foundation

SatNOGS COMMS
Interface Control Document

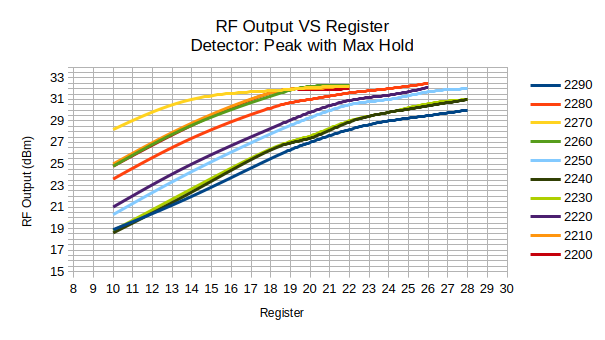
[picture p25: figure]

Figure 7.14: TX RF power vs AT86RF215 TX register on S-Band radio

The LO is selected according to the following table Table 7.5. The frequency step is 400Hz in the range 2200MHz to 2290MHz as defined by AT86RF215 IC. Option:Fine frequency step is possible after request.

LO (MHz) | IF (MHz) | RF (MHz) | Image (MHz)
182 | 2472 | 2290 | 2654
182 | 2462 | 2280 | 2644
216 | 2486 | 2270 | 2702
216 | 2476 | 2260 | 2692
216 | 2466 | 2250 | 2682
216 | 2456 | 2240 | 2672
216 | 2446 | 2230 | 2662
216 | 2436 | 2220 | 2652
216 | 2426 | 2210 | 2642
216 | 2416 | 2200 | 2632

Table 7.5: Look-up Table of LO frequencies of Transmitter

The mix current register of the RF mixer is set to 1.

### 7.3.4 S-Band Radio-Receiver

In the same manner with section subsection 7.3.2 are following the diagrams, Figure 7.15 and Figure 7.16.

Version 1.6 | 35 of 45 | © Libre Space Foundation

SatNOGS COMMS
Interface Control Document

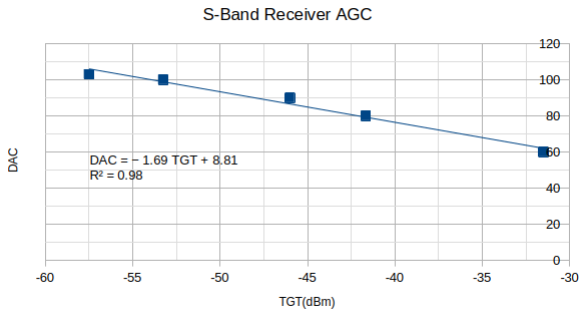
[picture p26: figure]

Figure 7.15: S-Band AGC-ON, DAC 8-bit

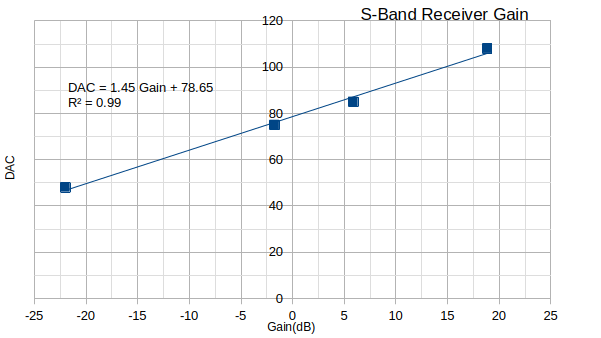
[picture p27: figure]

Figure 7.16: S-Band AGC-OFF, DAC 8-bit

The suggested mode is AGC ON with TGT level −55dBm to achieve the largest dynamic range of 40dB. Some critical characteristics:

Noise Figure (dB) | 2.2
Maximum input (dBm) | +27

Table 7.6: S-Band receiver

The TGT level is measured by using the RSSI of AT86RF215 with tolerance of ±5dB. The following table, Table 7.7, shows the DC power consumption in different RF input when the AGC in enabled and the output target is set on -52dBm ±5dB.

Version 1.6 | 36 of 45 | © Libre Space Foundation

SatNOGS COMMS
Interface Control Document
RF input (dBm) | RSSI (dBm) | Gain (dB) | DC power (W)
-20 | -48 | -28 | 2.22
-30 | -51 | -21 | 2.27
-40 | -51 | -11 | 2.34
-50 | -52 | -2 | 2.45
-60 | -52 | 8 | 2.57
-70 | -52 | 18 | 2.7
-80 | -59 | 21 | 2.83
-90 | -70 | 20 | 2.83
-100 | -78 | 22 | 2.8
-110 | -88 | 22 | 2.84

Table 7.7: RX S-Band Radio dynamic range and DC power consumption, AGC ON with TGT -52dBm

The measurements are done:

- with CW RF input signal
- by using the wide BPF
- temperature: 25 ◦C
- Dwell time: 60secs
- the DC power consumption is measured with joulescope and it is the average value of plateau, Figure 7.6

The LO is selected according to the following table Table 7.8. The frequency step is 400Hz in the range 2025MHz to 2110MHz as defined by AT86RF215 IC. Option:Fine frequency step is possible after request.

Image
(MHz)

IF
(MHz)

LO
(MHz)

RF
(MHz)

5th
LO
(MHz)

6th
LO
(MHz)

7th
LO
(MHz)
1635 | 2415 | 390 | 2025 | 1950 | 2340 | 2730
1640 | 2420 | 390 | 2030 | 1950 | 2340 | 2730
1650 | 2430 | 390 | 2040 | 1950 | 2340 | 2730
1660 | 2440 | 390 | 2050 | 1950 | 2340 | 2730
1670 | 2450 | 390 | 2060 | 1950 | 2340 | 2730
1706 | 2434 | 364 | 2070 | 1820 | 2184 | 2548
1716 | 2444 | 364 | 2080 | 1820 | 2184 | 2548
1726 | 2454 | 364 | 2090 | 1820 | 2184 | 2548
1736 | 2464 | 364 | 2100 | 1820 | 2184 | 2548
1746 | 2474 | 364 | 2110 | 1820 | 2184 | 2548

Table 7.8: Look-up Table of LO frequencies of Receiver

Version 1.6 | 37 of 45 | © Libre Space Foundation

SatNOGS COMMS
Interface Control Document

The mix current register of the RF mixer is set to 1.
Another important aspect is the BER performance of receiver. The following diagram and table, Figure 7.17 and Table 7.9, present the receiver sensitivity in different modulations.

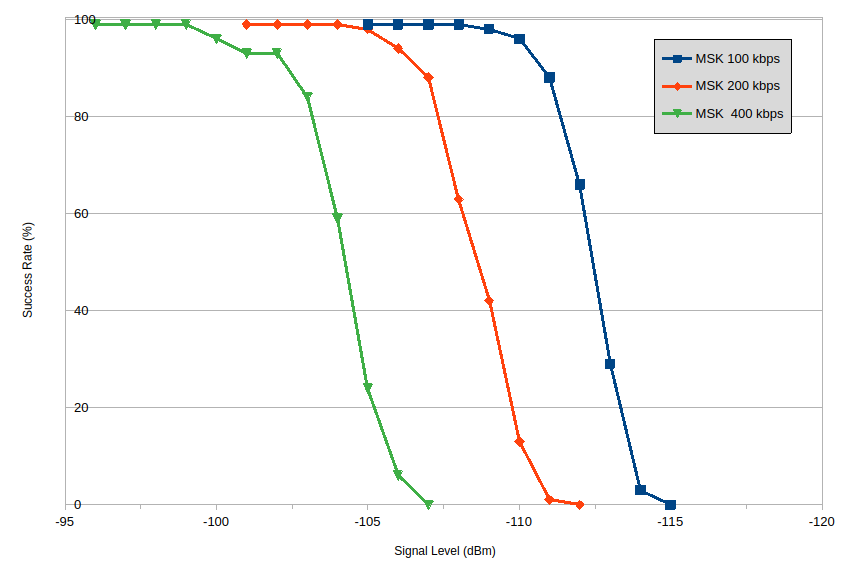
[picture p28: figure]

Figure 7.17: S-Band Frame success rate for various signal levels

Modulation | ∆f (kHz) | Success Rate | Signal Level (dBm)
MSK, 400ksps | ±60 | 1100 of 1100 | -96

Table 7.9: RX S-Band Radio Frequency offset sensitivity

Note:Better sensitivity is under investigation by the SatNOGS COMMS software team.

Version 1.6 | 38 of 45 | © Libre Space Foundation

SatNOGS COMMS
Interface Control Document

# 8. Environmental Specifications

This chapter outlines the system specifications related to its operational environment.

## 8.1 Operational Temperature

Based on the maximum and minimum operational temperatures of its components, the operational temperatures of SatNOGS COMMS range from −20° to 60° C. A component-level analysis is provided here. (https://cloud.libre.space/s/EdtgG9F3eb9kys9) As one can notice in the analysis, only a few resistors, capacitors, and inductors have been studied as samples, yet the analysis includes all the more complex integrated circuits. Additionally, a report from the most recent TVAC test can be found here. (https://gitlab.com/librespacefoundation/satnogs-comms/satnogs-comms-design-doc/-/jobs/artifacts/master/raw/build/environmental-test-report.pdf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)

## 8.2 Vibration Environment

The report from the most recent vibration test can be found here. (https://gitlab.com/librespacefoundation/satnogs-comms/satnogs-comms-design-doc/-/jobs/artifacts/master/raw/build/environmental-test-report.pdf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)

## 8.3 Electromagnetic Compatibility

### 8.3.1 Possible EM Emitters

Listed in Table 8.1 are potential EMI emitters on the board. This list mostly serves as a reference in case EMC debugging is required, because if detailed emission characterization is required (for example for a sensitive on—board payload), the emissions spectrum from the EMC test shall be used. Harmonics of the frequencies listed below are also possible to appear.
The report from the most recent EMC test is provided here. (https://gitlab.com/librespacefoundation/satnogs-comms/satnogs-comms-design-doc/-/jobs/artifacts/master/raw/build/emc-test-report.pdf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) Note that this test was conducted on SatNOGS COMMS v0.3.1. The upcoming SatNOGS COMMS v0.3.2 includes an EMI filter on the power input, which aims to alleviate the emissions which violate the limits in the provided test report.
Version 1.6 | 39 of 45 | © Libre Space Foundation

SatNOGS COMMS
Interface Control Document
Possible Emitter | Frequency
3.3V SMPS | 1.2 MHz
5V SMPS | 1.0 MHz
FPGA SoM 1V SMPS | 2.5 MHz
FPGA SoM 1.8V SMPS | 2.5 MHz
MCU HSE Crystal | 32 MHz
MCU LSE Crystal | 32.768 kHz
RF Transceiver Crystal | 26 MHz
FPGA Crystal | 100 MHz
LVDS | 64 MHz
RGMII | Depends on selected bus clock frequency
MCU-FPGA SPI | Depends on selected bus clock frequency
MCU-Transceiver SPI | Depends on selected bus clock frequency
Bus SPI | Depends on selected bus clock frequency
Bus UART | Depends on selected data rate
Bus I2C | Depends on selected bus clock frequency
SMBus | Depends on selected bus clock frequency
CAN-FD | Depends on selected data rate
CAN 2.0 | Depends on selected data rate

Table 8.1: Possible EMI emitters list

### 8.3.2 Grounding

The PCB is grounded through the PC-104 connector. So, there are no deliberate structure currents because the system has a single path to the satellite common ground (through the PC-104 connector). This grounding architecture is selected according to the NASA electrical grounding architecture technical handbook[9]. It must, however, be noted that the grounding of the EMI shield is not optimal. Instead of being connected to the satellite’s chassis ground (which, in turn, is connected to the common ground), the EMI shield is connected to the SatNOGS COMMS system ground and then to the satellite’s ground through the PC-104 connector. This structure results in a larger impedance on the path between the EMI shield and the common ground. Finally, it is noted that the ground of the RG ports is connected to the system ground.

## 8.4 Radiation Tolerance

Besides the power protection features aiming to increase radiation hardness against single event effects, SatNOGS COMMS employs aluminum shielding to protect its components from total ionizing dose faults. An analysis for a 6-year mission in a LEO orbit is provided in [10].

Version 1.6 | 40 of 45 | © Libre Space Foundation

SatNOGS COMMS
Interface Control Document

# 9. Material List

The list of materials contained in the SatNOGS COMMS system is provided here. (https://cloud.libre.space/s/SaeYA93L69b83R3)

Version 1.6 | 41 of 45 | © Libre Space Foundation

SatNOGS COMMS
Interface Control Document

# 10. Interfaces Data Sheet

INTERFACE DATA SHEET
| I/F Designation: | DC Power interface
ID | Source Circuit Specification | Ver | Iss
-1 | Bus voltage | 5.5V-30V input range
-2 | Bus current | 1.6A max @ 12V Bus voltage
-3 | Response to bus undervolt-age | All loads except MCU switch off automatically MCU is deactivated at 3.2V Bus voltage
-4 | Bus voltage (anomaly): | The load shall not be damaged when subjected to any bus voltage in the range 0V to 30V, steady-state or at any rate of change.

Table 10.1: DC Power Interface characteristics

INTERFACE DATA SHEET
| I/F Designation: | SPI interface
ID | Voltage, data rate and timing specification | Ver | Iss
-1 | Data rate | 8 Mbps for 3m total bus length between devices
-2 | Voltage range | 0V–3.3V
-3 | Voltage tolerance | -0.3V–5.5V
-4 | SPI clock frequency | Slave receiver mode: 100MHz max Slave mode transmitter/full duplex: 31MHz Slave mode transmitter/full duplex: 25MHz
-5 | NSS setup time | Min 2ns
-6 | NSS hold time | Min 1ns
-7 | Data input setup time | Min 2ns
-8 | Data input hold time | Min 1ns
-9 | Data input hold time | 1ns
-10 | Data output access time | 9ns–27ns
-11 | Data output disable time | Max 5ns
-12 | Data output valid time | Max 16ns
-13 | Data output hold time | Min 9ns

Table 10.2: SPI Interface characteristics

Version 1.6 | 42 of 45 | © Libre Space Foundation

SatNOGS COMMS
Interface Control Document

INTERFACE DATA SHEET
| I/F Designation: | CAN interface
ID | CAN Bus characteristics | Ver | Iss
-1 | Bus 1 | Compliant with ISO 11898–1[11] (CAN protocol specification version 2.0 part A, B) and CAN FD protocol specification version 1.0 Supports time triggered CAN (TT-FDCAN) specified in ISO 11898–4[12]
-2 | Bus 2 | Compliant with ISO 11898–1[11] (CAN protocol specification version 2.0 part A, B) and CAN FD protocol specification version 1.0
-3 | Receiver common mode in-put voltage | +/-12V
-4 | Bus fault protection | +/-58V
-5 | Max differential voltage be-tween CANH and CANL | +/-45V
-6 | Bus termination | 120 Ω at each end of the bus. Split termination is supported

Table 10.3: CAN Interface characteristics

INTERFACE DATA SHEET
| I/F Designation: | Antenna interface
ID | RF characteristics | Ver | Iss
-1 | UHF Impedance | 50 Ω
-2 | S-Band impedance | 50 Ω
Deployment control
-3 | Output type | Push-pull or Open-drain
-4 | Output voltage | Push-pull: 3.3V Open-drain: 5V
-5 | Output current | Max 18mA
Deployment detection
-6 | Input type | Pull-Up, Pull-Down, Floating or Analog
-7 | Input voltage | Nominal 3.3V (reference voltage for analog) Tolerant 5V (only Digital)
-8 | High threshold | 2V
-9 | Low threshold | 0.8V
-10 | Pull-up/Pull-down resistor | 40kΩ±10kΩ

Table 10.4: Antenna Interface characteristics

INTERFACE DATA SHEET
| I/F Designation: | External Clock interface
ID | RF characteristics, Voltage and timing specification | Ver | Iss
-1 | Impedance: 1PPS | 50 Ω
-2 | Impedance: RFFE-26MHz | 50 Ω
-3 | Voltage Level: 1PPS | 0V and 3.3V
-4 | Voltage Level: RFFE-26MHz | peak-to-peak amplitude: 600mV to 1600mV
-5 | Signal Type: 1PPS | Pulse
-6 | Signal Type: RFFE-26MHz | Pulse or Clipped Sine

Table 10.5: External Clock, 1PPS and 26MHz characteristics

Version 1.6 | 43 of 45 | © Libre Space Foundation

SatNOGS COMMS
Interface Control Document

INTERFACE DATA SHEET
| I/F Designation: | RGMII
ID | RGMII characteristics | Ver | Iss
-1 | Signal characteristics | Gigabit Ethernet Controller compliant with IEEE 802.3–2008 standard [2]
-2 | Data rate | 10/100/1000 Mbps
-3 | Voltage range | 0V 1.8V

Table 10.6: RGMII Interface characteristics

INTERFACE DATA SHEET
| I/F Designation: | UART
ID | UART characteristics | Ver | Iss
-1 | Type | Asynchronous
-2 | Data rate | User defined
-3 | Voltage range | 0V to 3.3V

Table 10.7: UART Interface characteristics

INTERFACE DATA SHEET
| I/F Designation: | I2C
ID | I2C characteristics | Ver | Iss
-1 | Type | Bidirectional
-2 | Data rate | 0.1/0.4/1.0 Mbps
-3 | Voltage range | 0V to 3.3V

Table 10.8: I2C Interface characteristics

Version 1.6 | 44 of 45 | © Libre Space Foundation

SatNOGS COMMS
Interface Control Document

# References

[1] LibreCube. LibreCube project. (https://librecube.gitlab.io/)
[2] IEEE. Ieee standard for information technology–telecommunications and information exchange between systems–local and metropolitan area networks–specific requirements part 3: Carrier sense multiple access with collision detection (csma/cd) access method and physical layer specifications, 2008.
[3] Libre Space Foundation. SatNOGS COMMS Firmware. (https://gitlab.com/librespacefoundation/satnogs-comms/satnogs-comms-software-mcu)
[4] Zephyr RTOS, (https://www.zephyrproject.org/) 2024.
[5] Libre Space Foundation. SatNOGS COMMS Software Documentation. (https://librespacefoundation.gitlab.io/satnogs-comms/satnogs-comms-software-mcu)
[6] Libre Space Foundation. SatNOGS COMMS Control Library. (https://gitlab.com/librespacefoundation/satnogs-comms/libsatnogs-comms)
[7] CCSDS. CCSDS Recommended Standard for XML Telemetric and Command Exchange, CCSDS 660.0-B-2. 2020.
[8] Libre Space Foundation. SatNOGS COMMS YAMCS Control Software. (https://gitlab.com/librespacefoundation/satnogs-comms/satnogs-comms-yamcs)
[9] NASA. ELECTRICAL GROUNDING ARCHITECTURE FOR UN-MANNED SPACECRAFT, (https://s3vi.ndc.nasa.gov/ssri-kb/static/resources/NASA-HDBK-4001.pdf) 1998.
[10] SatNOGS COMMS radiation shield analysis. (https://gitlab.com/librespacefoundation/satnogs-comms/satnogs-comms-hardware/-/issues/464)
[11] ISO/TC 22/SC 31. Road vehicles — Controller area network (CAN) — Part 1: Data link layer and physical signalling, (https://www.iso.org/standard/63648.html) 2015.
[12] ISO/TC 22/SC 31. Road vehicles — Controller area network (CAN) — Part 4: Time-triggered communication, (https://www.iso.org/standard/36306.html) 2004.
Version 1.6 | 45 of 45 | © Libre Space Foundation

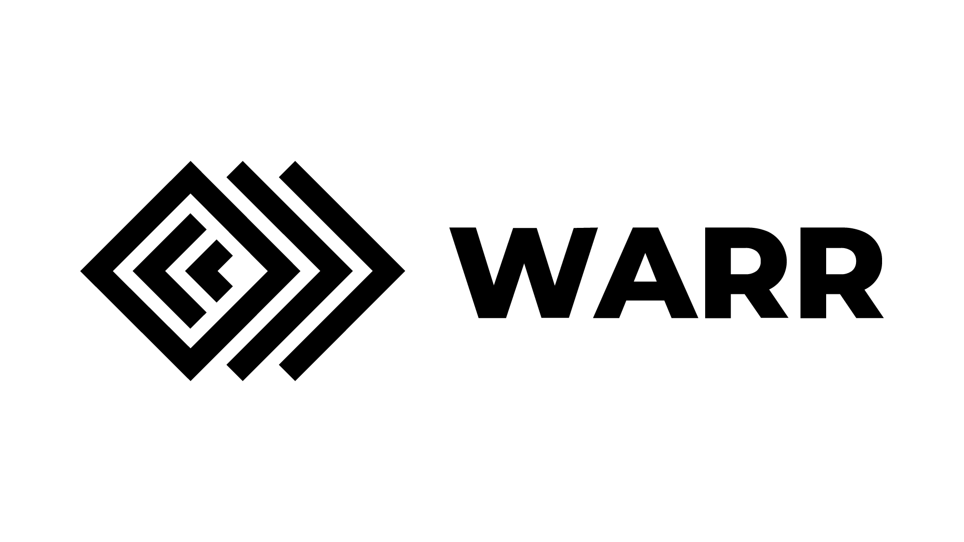
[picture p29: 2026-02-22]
docs/warr.png

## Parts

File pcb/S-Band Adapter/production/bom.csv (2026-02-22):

Designator | Footprint | Quantity | Value | LCSC Part #
C1 | 0805 | 1 | 100nF
H101 | PC_104 | 1 | PC_104
J1, J5 | CT3151SP2 | 2 | CT3151SP-2
J2 | SAMTEC_FTSH-107-01-L-DV-K-A | 1 | FTSH-107-01-L-DV-K-A
J3 | SAMTEC_ERF8-030-05.0-L-DV-TR | 1 | ERF8-030-05.0-L-DV-TR
J4 | MOLEX_532611071 | 1 | 532611071
S1 | 430152050826 | 1 | 430152050826

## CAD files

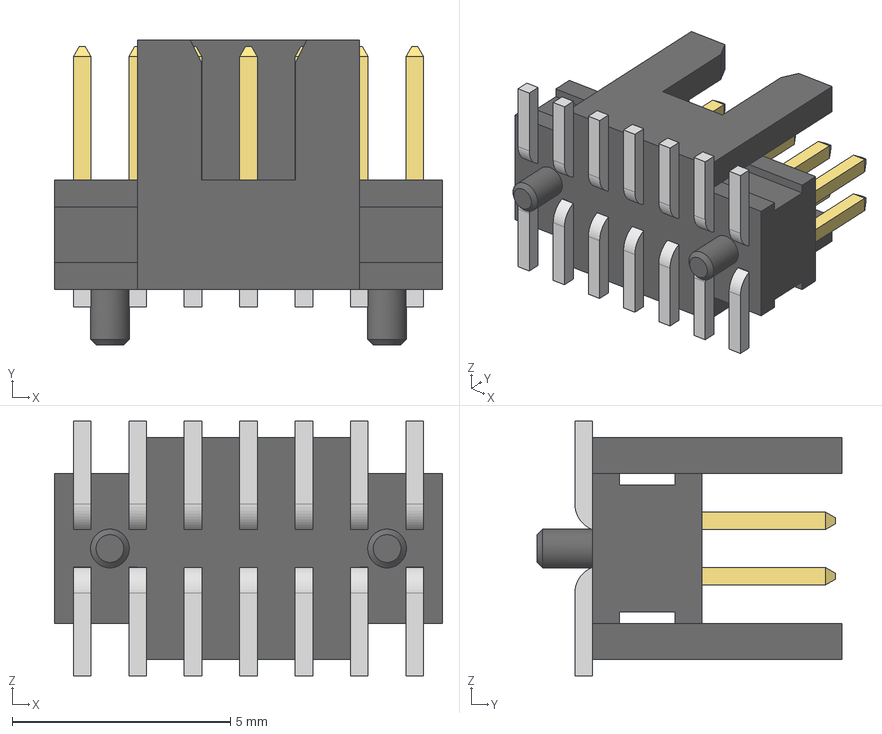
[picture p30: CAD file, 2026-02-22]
components/FTSH-107-01-L-DV-K-A/FTSH-107-01-L-DV-K-A.step
8.89 x 6.98 x 5.84 mm
FTSH-107-01-L-DV-K-A_body
FTSH-107-01-L-DV-K-A_pins1
FTSH-107-01-L-DV-K-A_pins2

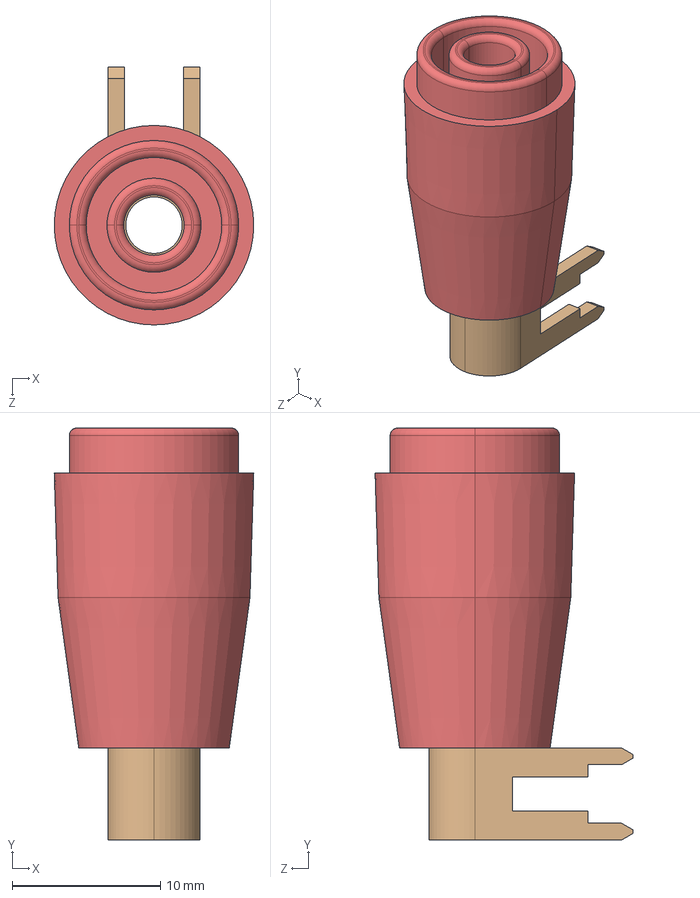
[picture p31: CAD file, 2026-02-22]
components/LIB_CT3151SP-2/3D/CT3151SP-2.stp
13.5 x 27.8 x 17.4 mm

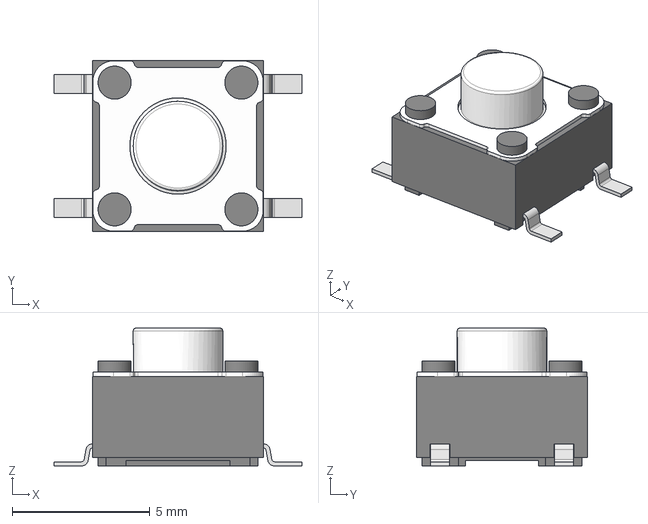
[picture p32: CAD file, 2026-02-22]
components/430152050826/430152050826.step
9.00 x 6.20 x 5.00 mm

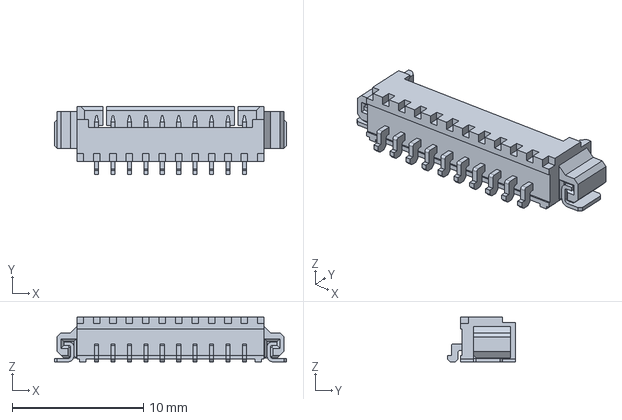
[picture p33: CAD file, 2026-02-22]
components/532611071/532611071.step
17.6 x 5.20 x 3.40 mm

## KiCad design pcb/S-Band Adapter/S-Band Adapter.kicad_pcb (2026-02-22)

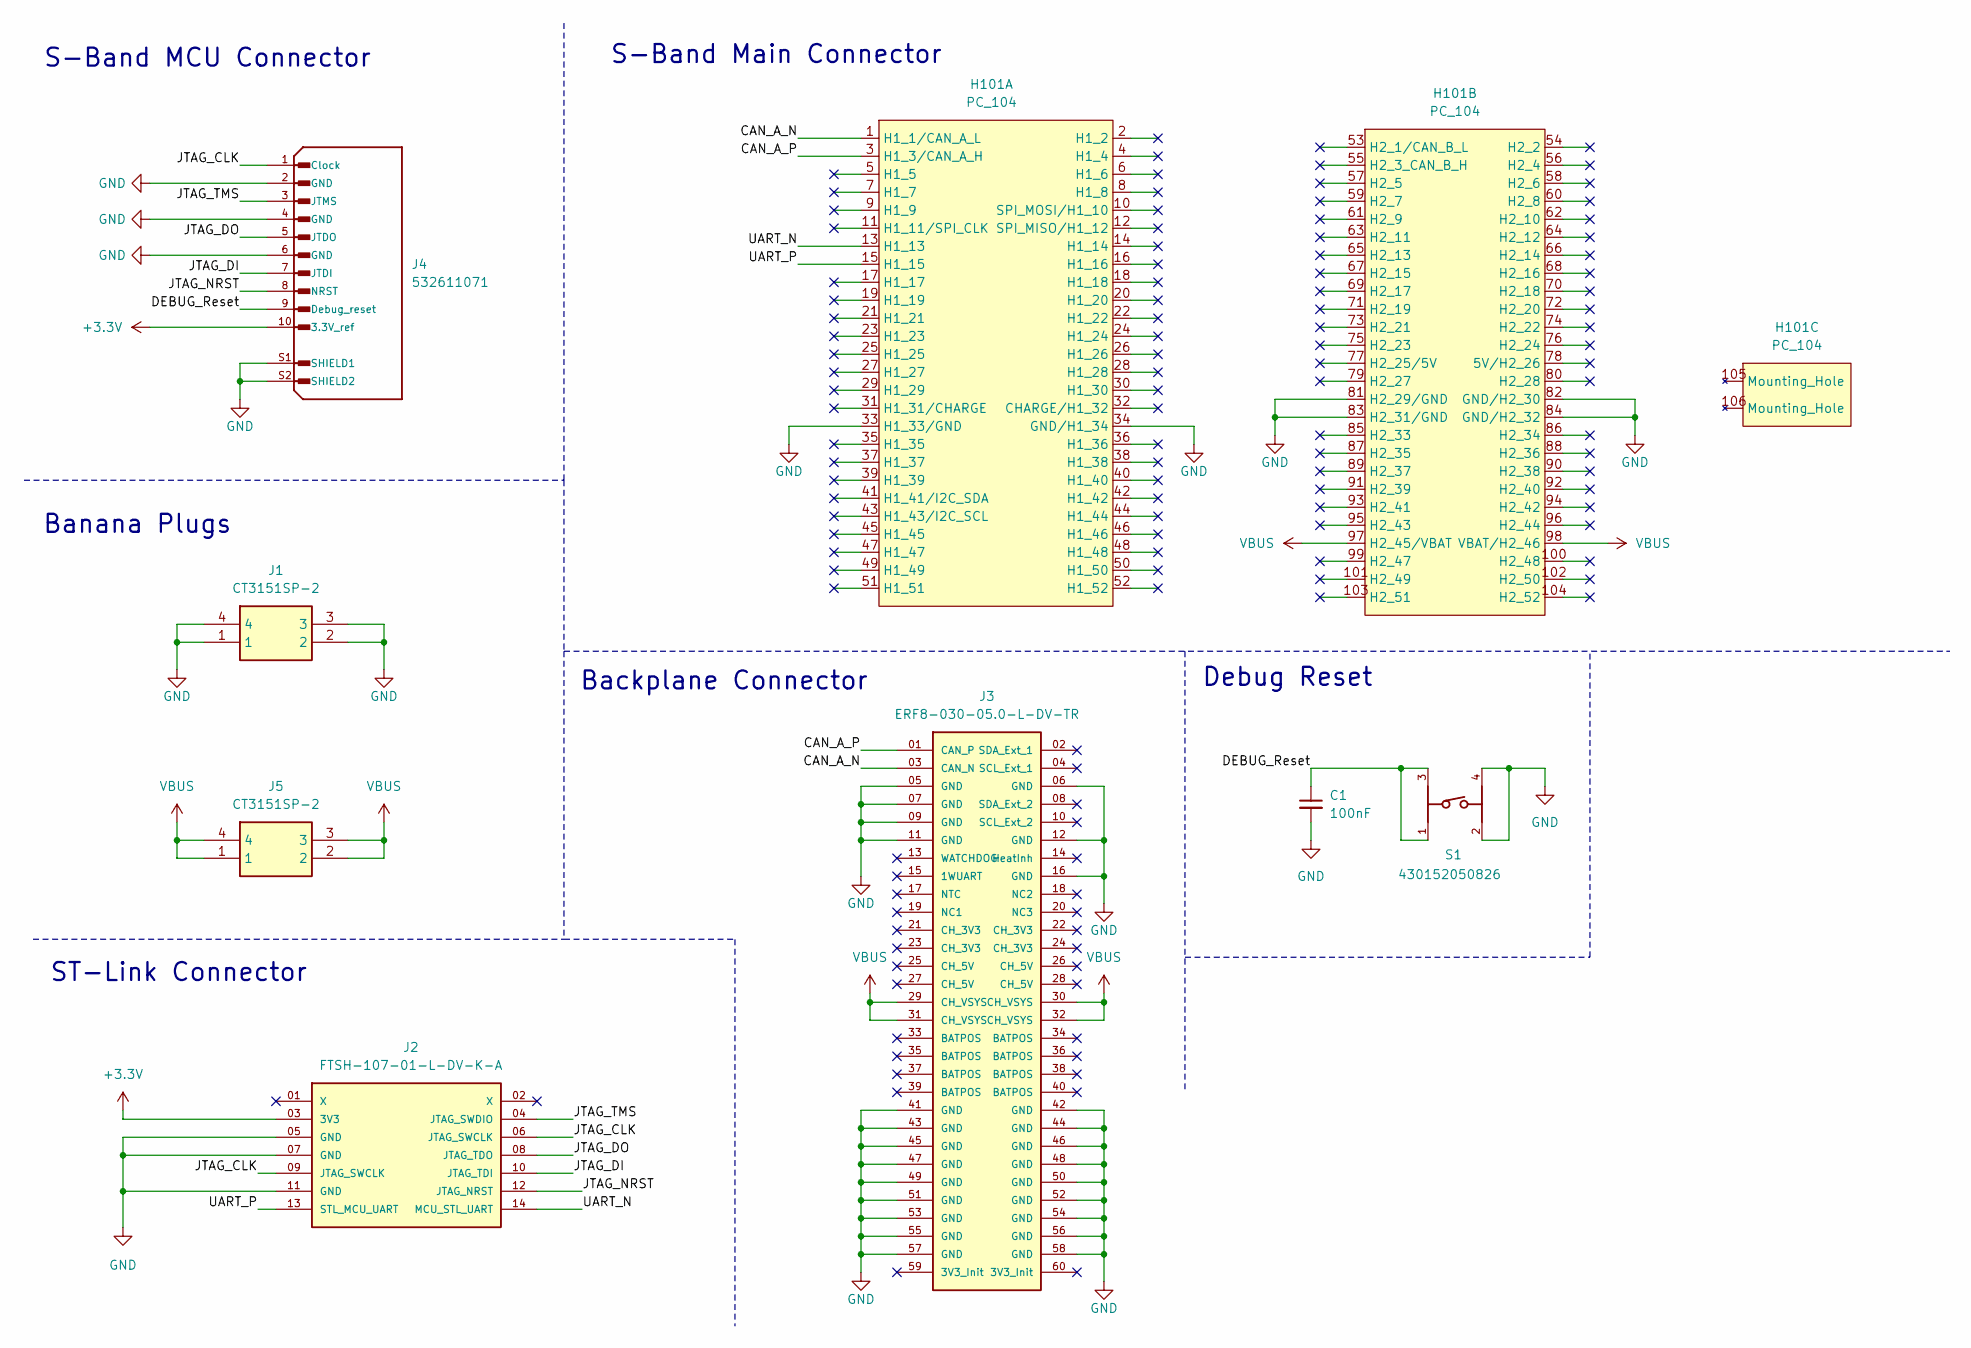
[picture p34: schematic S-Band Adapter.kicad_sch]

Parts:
C1: 100nF; C_0805_2012Metric_Pad1.18x1.45mm_HandSolder
H101: PC_104; PartNumber ESQ-126-39-x-D
J1, J5: CT3151SP-2; CT3151SP2; Manufacturer_Part_Number CT3151SP-2; Mouser Part Number 510-CT3151SP-2
J2: FTSH-107-01-L-DV-K-A; SAMTEC_FTSH-107-01-L-DV-K-A; PARTREV H; DigiKey_Part_Number FTSH-107-01-L-DV-K-A-ND
J3: ERF8-030-05.0-L-DV-TR; SAMTEC_ERF8-030-05.0-L-DV-TR; DigiKey_Part_Number SAM13580CT-ND
J4: 532611071; MOLEX_532611071; PARTREV J; DigiKey_Part_Number WM7628CT-ND
S1: 430152050826; DigiKey_Part_Number 732-6993-1-ND

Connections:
+3.3V: J2.03 (3V3), J4.10 (3.3V_ref)
/CAN_A_N: H101.1 (H1_1/CAN_A_L), J3.03 (CAN_N)
/CAN_A_P: H101.3 (H1_3/CAN_A_H), J3.01 (CAN_P)
/DEBUG_Reset: C1.1, J4.9 (Debug_reset), S1.1, S1.3
/JTAG_CLK: J2.06 (JTAG_SWCLK), J2.09 (JTAG_SWCLK), J4.1 (Clock)
/JTAG_DI: J2.10 (JTAG_TDI), J4.7 (JTDI)
/JTAG_DO: J2.08 (JTAG_TDO), J4.5 (JTDO)
/JTAG_NRST: J2.12 (JTAG_NRST), J4.8 (NRST)
/JTAG_TMS: J2.04 (JTAG_SWDIO), J4.3 (JTMS)
/UART_N: H101.13 (H1_13), J2.14 (MCU_STL_UART)
/UART_P: H101.15 (H1_15), J2.13 (STL_MCU_UART)
GND: C1.2, H101.33 (H1_33/GND), H101.34 (GND/H1_34), H101.81 (H2_29/GND), H101.82 (GND/H2_30), H101.83 (H2_31/GND), H101.84 (GND/H2_32), J1.1, J1.2, J1.3, J1.4, J2.05 (GND), J2.07 (GND), J2.11 (GND), J3.05 (GND), J3.06 (GND), J3.07 (GND), J3.09 (GND), J3.11 (GND), J3.12 (GND), J3.16 (GND), J3.41 (GND), J3.42 (GND), J3.43 (GND), J3.44 (GND), J3.45 (GND), J3.46 (GND), J3.47 (GND), J3.48 (GND), J3.49 (GND), J3.50 (GND), J3.51 (GND), J3.52 (GND), J3.53 (GND), J3.54 (GND), J3.55 (GND), J3.56 (GND), J3.57 (GND), J3.58 (GND), J4.2 (GND), J4.4 (GND), J4.6 (GND), J4.S1 (SHIELD1), J4.S2 (SHIELD2), S1.2, S1.4
VBUS: H101.97 (H2_45/VBAT), H101.98 (VBAT/H2_46), J3.29 (CH_VSYS), J3.30 (CH_VSYS), J3.31 (CH_VSYS), J3.32 (CH_VSYS), J5.1, J5.2, J5.3, J5.4

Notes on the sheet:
ST-Link Connector
S-Band MCU Connector
Debug Reset
Banana Plugs
S-Band Main Connector
Backplane Connector

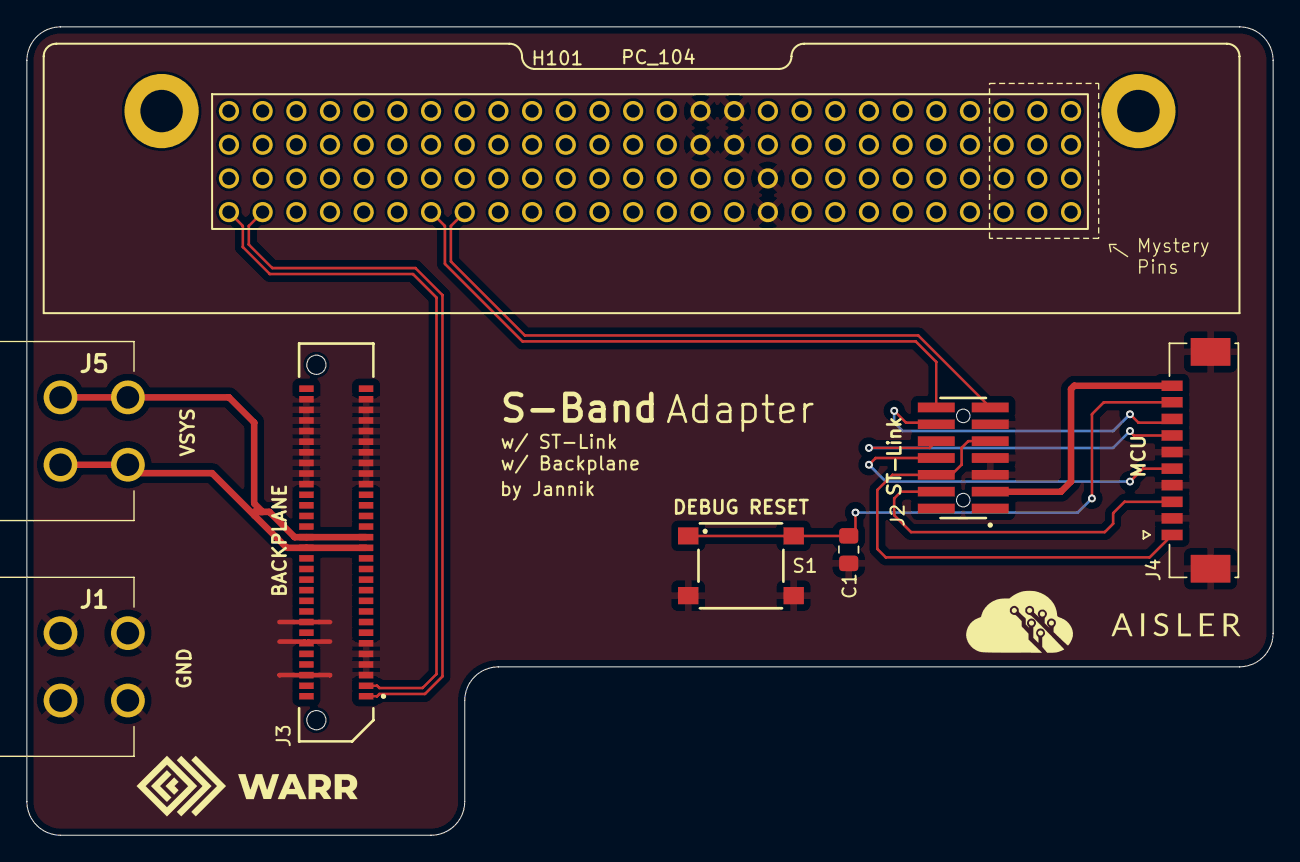
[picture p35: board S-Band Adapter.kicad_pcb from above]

Board: 2 copper layers, 94.0 x 61.0 mm, 8 parts (0 on the bottom side), 13 nets.

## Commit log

2026-02-22 Finished PCB
    [PC104-Breakout.kicad_pcb, PC104-Breakout.kicad_sch, S-Band Adapter.kicad_pcb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]
2026-02-22 Improved docs
    [S-Band Adapter.kicad_pcb]
2026-02-22 Fixed Pulling VSYS from BATPOS
    [S-Band Adapter.kicad_pcb, S-Band Adapter.kicad_sch]
2026-02-22 Improved 3.3V net track width
    [S-Band Adapter.kicad_pcb]
2026-02-22 Added Debug_Reset button & fixed VBAT label
    [430152050826.step, S-Band Adapter.kicad_pcb, S-Band Adapter.kicad_sch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]
2026-02-22 Updated pcb image
2026-02-22 Added aisler logo
    [S-Band Adapter.kicad_pcb]

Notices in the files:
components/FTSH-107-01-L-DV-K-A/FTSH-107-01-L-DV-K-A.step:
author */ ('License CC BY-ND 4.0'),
